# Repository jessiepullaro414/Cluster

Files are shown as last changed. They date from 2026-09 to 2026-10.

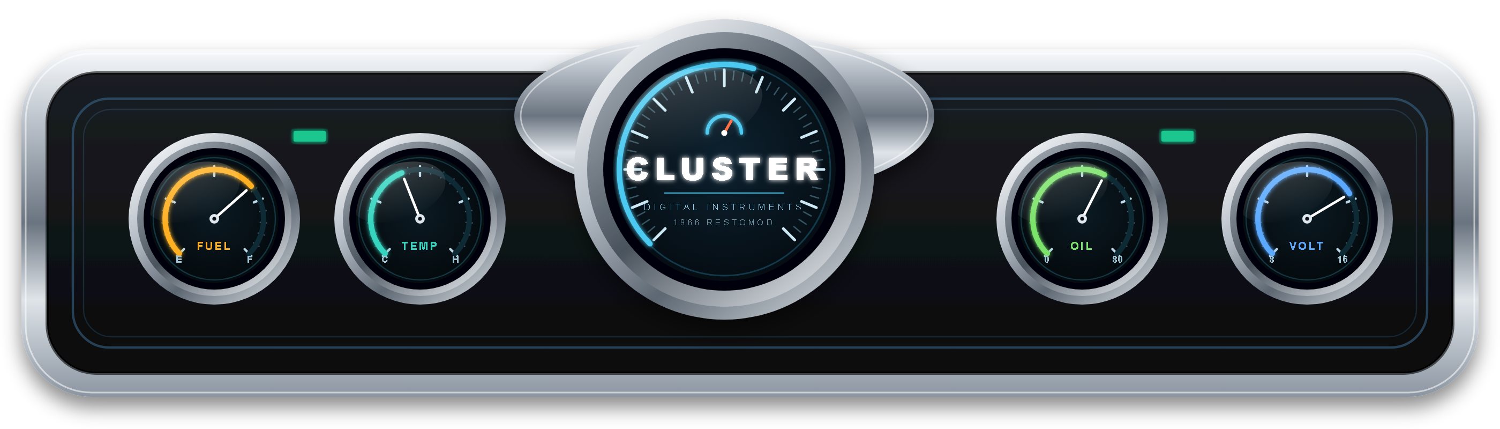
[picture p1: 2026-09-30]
media/cluster-dashboard.png

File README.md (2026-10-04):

# Cluster

Digital restomod instrument cluster for a 1966 Mustang: round displays in the stock round holes, custom reprinted faceplate, stock outer dash opening (457.2 x 116.69mm hard limit, 441.09 x 105.54mm inner).

The center gauge runs Android Automotive; the four small gauges are driven by a separate MCU board. Both boards share a CAN bus with `ecu-pcb`.

## Boards

| Dir | Role | Core | Board |
|---|---|---|---|
| [display/](display/) | Android center gauge | Toradex Verdin iMX95 SoM, 4in 800-nit round MIPI-DSI panel | about 152 x 102mm |
| [gauges/](gauges/) | 4 small aux gauges, resistive sender front end, Hall speed, tach and six 12 V indicator-lamp inputs | NXP S32K144, 4x GC9A01 round SPI | 447.1 x 58.3mm |

**Status: prototype, not yet ordered.** Both boards are routed with 0 unconnected nets and have generated BOMs (`ClusterDisplay_BOM.html`, `ClusterGauges_BOM.html`). display/ is ERC-clean (0 violations); gauges/ shows 4 known ERC items (a SWCLK pin, the MCU and buck supply pins flagged as undriven, and a `+5V` power-flag note). DRC on display/ reports 10 `solder_mask_bridge` errors that are the intentional open polarity jumpers JP1/JP2, plus silkscreen and library-copy warnings. Nothing has been fabricated, powered or firmware-tested. Mechanical fit in the dash is not yet checked against a 3D model, and gauges/ (447.1 mm) is wider than the 441.09 mm inner opening dimension, within the 457.2 mm outer limit.

## How the boards talk

gauges/ is the gateway. It is the only board that touches the car CAN bus (CAN0, receive-only in firmware) and it forwards filtered values to display/ over a private two-node CAN link (gauges/ CAN1 to display/ CAN). Android therefore cannot transmit on the vehicle bus. The protocol (`protocol/can_protocol.py`, revision 2) generates the DBC, a spec and a C header; the private link carries a rolling counter and CRC-8, and the car-bus side has a selectable Haltech V2 profile. Speed comes from a Hall-effect sender on gauges/ (for cable-driven cars) or from the ECU over CAN. gauges/ also reads six 12 V-active indicator lamps (left/right turn, high beam, brake, alternator, oil; each has a DNP pull-up for a ground-switched lamp) and a tach input (ECU or coil-driver output; coil-negative on a points ignition is not validated), sent to display/ in the `Indicators` message (which also carries the dimmer level) and the `Rpm` signal. display/ has a rotary-dial input (J11), an ignition wake circuit, and bench headers for the A55 console UART (J12), USB (J13), JTAG (J8) and buttons (J9).

## Known limits of the layouts

- Both boards are four-layer with GND on In1 and +5V / +3V3 poured on In2, but they are not solid planes: slow signals were routed on the inner layers by the autorouter and the pours fill around them. On display/ about 925 mm of signal wiring sits on In1 (none inside the DSI corridor, none under the +5V buck or the backlight boost, about 17 mm under the panel-bias converter) and about 790 mm on In2. On gauges/ about 3.9 m sits on In1 and 5.1 m on In2, because it is a 447 mm board with long runs to four displays. Forbidding signals on In1 left 6 to 122 connections unrouted, so it was not adopted.
- The panel DSI lanes on display/ are routed by `dsi_route.py` (about 10.6 to 11.2 mm per leg, at most 0.6 mm skew inside a pair) with an estimated 100 ohm differential geometry that has not been checked with a field solver.
- The panel connector, the panel polarity jumpers and the wake-pin polarity are unconfirmed (see `fab/README.md`).

Open items and rationale live in the working plan, not here. Panel: TSD TST040HDBC-42 (4in round, 800 nits, -30..+80C, fits the opening uncropped). Known TBDs: harness connectors J2/J3/J8/J9 on display/, the panel's unresolved +/-6.5V pin polarity (open solder jumpers JP1/JP2), CAN protocol, firmware.

## Workflow

Everything is generated from scripts. Never hand-edit the KiCad files; change the script and regenerate. In `display/` or `gauges/`:

```
python build_schematic.py   # schematic + ERC self-checks
python build_pcb.py         # placement + DRC-style self-checks
python route_board.py       # FreeRouting (display/ also adds the DSI pairs), verified against real kicad-cli DRC
python ../run_drc.py <Board>.kicad_pcb
python build_bom.py         # BOM with coverage/value-spelling checks
```

`route_board.py` needs `tools/freerouting-2.2.4.jar` (gitignored, ~57MB; download from the FreeRouting releases) and a JRE.

## Archive

[archive/](archive/) holds superseded work kept for reference only, not maintained:

- `single-board-s32k144-bt817aq/`: the original one-board design (S32K144 + BT817AQ + round ST7701S speedo + 4 GC9A01), fully routed 252/252 before the Android pivot.
- `.../sense-abandoned-bar-panel-attempt/`: an unfinished CAN-only sensor board from the abandoned wide bar-panel direction.

Scripts there use their old relative paths (`tools/`, `run_drc.py`) and will need adjusting to run.

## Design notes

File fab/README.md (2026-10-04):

# Fab package

Generated by `python fab/build_fab.py` from the routed boards. It refuses to package a board that has unconnected nets or an unexpected DRC category.

Per board (`fab/display/`, `fab/gauges/`):

| File | What it is |
|---|---|
| `<board>_fab.zip` | Gerbers (Protel extensions, X2) and Excellon drill (plated and non-plated separate). Upload this to the board house. |
| `<board>_bom.csv` | One line per orderable part: MPN, manufacturer, quantity, designators. Source for a Mouser/DigiKey cart. |
| `<board>_pos.csv` | Pick-and-place, only needed if the fab assembles. |
| `report.txt` | DRC status and counts. |

Also `fab/combined_bom.csv`: both boards' parts in one cart-ready list (quantities per board, so multiply by the number of boards you build).

## Order settings (both boards)

Checked against JLCPCB's published 4-layer capabilities (min trace/space 0.09 mm, min drill 0.15 mm, via 0.15/0.25 mm, silkscreen text at least 1.0 mm high and 0.15 mm stroke). These boards use 0.2 mm tracks and clearances, 0.3/0.6 mm vias, a smallest drill of 0.2 mm, and 1.0 mm / 0.15 mm silkscreen text, so they sit inside those limits.

- Layers: 4. Thickness: 1.6 mm. Outer copper 1 oz, inner copper 0.5 oz.
- Surface finish: **ENIG**. The panel connector is 0.3 mm pitch and the MCU, buck and QFN parts are 0.5 mm pitch; HASL is not recommended.
- Solder mask and silkscreen: your choice (the layout is drawn for dark mask with white silk). Black mask with white silk suits the dash.
- Impedance control: **request it for display/ if the fab offers it, with the DSI pairs as the controlled pairs.** The four DSI pairs are 0.25 mm tracks with a 0.25 to 0.5 mm gap on F.Cu over the In1 ground plane, about 10.6 to 11.2 mm per leg, with at most 0.6 mm (about 4 ps) skew inside a pair. By the IPC-2141 approximation that is about 100 ohm differential for a 0.21 mm prepreg; that is an estimate, so use the fab's own calculator and stackup and adjust width and gap if it disagrees. The P leg of each pair hops to B.Cu for about 3 mm to swap polarity order between the connectors (two 0.6/0.3 mm vias), where the reference is In2 rather than ground. (An earlier version of this page called uncontrolled impedance acceptable; the corrected layout is short enough that it matters less, but it is still a high-speed pair.)
- Quantity: 5 of each is the usual minimum.

## Board sizes

- display/: about 152 x 102 mm.
- gauges/: 447 x 56 mm. Check the board house's maximum length for your chosen service (the long side is under 500 mm).

## What is still unconfirmed (could force a respin of display/)

1. The panel FPC connector (Hirose FH26-39S-0.3SHW) is inferred from the panel datasheet; the datasheet names no connector. Ask TSD (draft in `docs/rfq-drafts.md`).
2. The panel's +/-6.5 V pin polarity is contradictory in its datasheet; the board has open solder jumpers JP1/JP2 for either answer.
3. The Verdin wake-pin polarity is unstated; the circuit assumes a software-selectable edge.

gauges/ has no open hardware question other than the AutoMeter sender wiring (assumed harness-powered, signal and ground only).

## Parts

Every active part and connector has a real orderable part number. Passives come from `tools/passive_catalog.py`; entries marked PATTERN in the BOM follow the manufacturer's numbering scheme with neighbouring parts verified, and should be confirmed in the distributor cart. Live pricing and stock are not included.

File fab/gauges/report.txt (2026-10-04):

gauges fab package
  DRC: unconnected 0, accepted findings {'silk_edge_clearance': 4, 'lib_footprint_mismatch': 8, 'silk_overlap': 1, 'silk_over_copper': 1}
  parts 137, BOM lines 59, lines needing part selection 0
  gerbers: ['ClusterGauges-B_Cu.gbl', 'ClusterGauges-B_Mask.gbs', 'ClusterGauges-B_Paste.gbp', 'ClusterGauges-B_Silkscreen.gbo', 'ClusterGauges-Edge_Cuts.gm1', 'ClusterGauges-F_Cu.gtl', 'ClusterGauges-F_Mask.gts', 'ClusterGauges-F_Paste.gtp', 'ClusterGauges-F_Silkscreen.gto', 'ClusterGauges-In1_Cu.g1', 'ClusterGauges-In2_Cu.g2', 'ClusterGauges-NPTH-drl_map.gbr', 'ClusterGauges-NPTH.drl', 'ClusterGauges-PTH-drl_map.gbr', 'ClusterGauges-PTH.drl', 'ClusterGauges-job.gbrjob']

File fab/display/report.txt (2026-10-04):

display fab package
  DRC: unconnected 0, accepted findings {'solder_mask_bridge(JP1/JP2 open jumpers, intended)': 10, 'lib_footprint_mismatch': 11, 'silk_overlap': 2, 'silk_over_copper': 4}
  parts 115, BOM lines 67, lines needing part selection 2
  gerbers: ['ClusterDisplay-B_Cu.gbl', 'ClusterDisplay-B_Mask.gbs', 'ClusterDisplay-B_Paste.gbp', 'ClusterDisplay-B_Silkscreen.gbo', 'ClusterDisplay-Edge_Cuts.gm1', 'ClusterDisplay-F_Cu.gtl', 'ClusterDisplay-F_Mask.gts', 'ClusterDisplay-F_Paste.gtp', 'ClusterDisplay-F_Silkscreen.gto', 'ClusterDisplay-In1_Cu.g1', 'ClusterDisplay-In2_Cu.g2', 'ClusterDisplay-NPTH-drl_map.gbr', 'ClusterDisplay-NPTH.drl', 'ClusterDisplay-PTH-drl_map.gbr', 'ClusterDisplay-PTH.drl', 'ClusterDisplay-job.gbrjob']

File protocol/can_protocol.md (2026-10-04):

# Cluster CAN protocol, rev 2 (proposal)

Generated by `can_protocol.py`; do not edit by hand.

gauges/ is the gateway: only it is on the car bus (listen-only). display/ talks to gauges/ over a private link. See the plan for the topology and the reasons.

## Private link (gauges/ <-> display/)

Little-endian, 500 kbit/s (proposed). Messages with `Counter` and `Crc8` end with a 4-bit rolling counter (bits 52-55) and CRC-8 SAE J1850 (poly 0x1D, init 0xFF, final XOR 0xFF) over bytes 0-6. Missing display heartbeat for 1500 ms means DisplayOffline.

| ID | Name | Sender | Period | DLC |
|---|---|---|---|---|
| 0x300 | VehicleMotion | GAUGES | 50 ms | 8 |
| 0x302 | VehicleFluids | GAUGES | 100 ms | 8 |
| 0x303 | Indicators | GAUGES | 100 ms | 8 |
| 0x301 | GaugesStatus | GAUGES | 1000 ms | 8 |
| 0x310 | PowerState | GAUGES | 500 ms | 8 |
| 0x400 | DisplaySettings | DISPLAY | 1000 ms | 8 |
| 0x410 | SpeedCalibration | DISPLAY | 1000 ms | 8 |
| 0x420 | InputConfig | DISPLAY | 1000 ms | 8 |
| 0x4F0 | DisplayHeartbeat | DISPLAY | 1000 ms | 8 |

### 0x300 VehicleMotion (GAUGES, 50 ms)

Consolidated motion data, chosen by gauges/ from the Hall input and the car bus.

| Signal | Start bit | Length | Scale | Offset | Range | Unit |
|---|---|---|---|---|---|---|
| SpeedKph | 0 | 16 | 0.1 | 0 | 0..400 | km/h |
| Rpm | 16 | 16 | 1 | 0 | 0..12000 | rpm |
| BatteryV | 32 | 16 | 0.01 | 0 | 0..20 | V |
| SpeedValid | 48 | 1 | 1 | 0 | 0..1 |  |
| RpmValid | 49 | 1 | 1 | 0 | 0..1 |  |
| BatteryValid | 50 | 1 | 1 | 0 | 0..1 |  |
| SpeedFromHall | 51 | 1 | 1 | 0 | 0..1 |  |
| Counter | 52 | 4 | 1 | 0 | 0..15 |  |
| Crc8 | 56 | 8 | 1 | 0 | 0..255 |  |

### 0x302 VehicleFluids (GAUGES, 100 ms)

Consolidated fluid data: ECU value if fresh, else local sender.

| Signal | Start bit | Length | Scale | Offset | Range | Unit |
|---|---|---|---|---|---|---|
| FuelPct | 0 | 16 | 0.01 | 0 | 0..100 | % |
| CoolantC | 16 | 16 signed | 0.1 | 0 | -40..150 | degC |
| OilKpa | 32 | 16 | 0.1 | 0 | 0..1000 | kPa |
| FuelValid | 48 | 1 | 1 | 0 | 0..1 |  |
| CoolantValid | 49 | 1 | 1 | 0 | 0..1 |  |
| OilValid | 50 | 1 | 1 | 0 | 0..1 |  |
| Counter | 52 | 4 | 1 | 0 | 0..15 |  |
| Crc8 | 56 | 8 | 1 | 0 | 0..255 |  |

### 0x303 Indicators (GAUGES, 100 ms)

Indicator-lamp states from the six 12 V lamp inputs on gauges/ (1 = lamp on after the per-channel polarity setting), sent every 100 ms and on every change.

| Signal | Start bit | Length | Scale | Offset | Range | Unit |
|---|---|---|---|---|---|---|
| TurnLeft | 0 | 1 | 1 | 0 | 0..1 |  |
| TurnRight | 1 | 1 | 1 | 0 | 0..1 |  |
| HighBeam | 2 | 1 | 1 | 0 | 0..1 |  |
| BrakeWarning | 3 | 1 | 1 | 0 | 0..1 |  |
| AlternatorWarning | 4 | 1 | 1 | 0 | 0..1 |  |
| OilWarning | 5 | 1 | 1 | 0 | 0..1 |  |
| DashLightsOn | 6 | 1 | 1 | 0 | 0..1 |  |
| DashDimmerPct | 8 | 8 | 1 | 0 | 0..100 | % |
| Counter | 52 | 4 | 1 | 0 | 0..15 |  |
| Crc8 | 56 | 8 | 1 | 0 | 0..255 |  |

### 0x301 GaugesStatus (GAUGES, 1000 ms)

Health, identity and where each value currently comes from.

| Signal | Start bit | Length | Scale | Offset | Range | Unit |
|---|---|---|---|---|---|---|
| FwMajor | 0 | 8 | 1 | 0 | 0..255 |  |
| FwMinor | 8 | 8 | 1 | 0 | 0..255 |  |
| FuelSenderOpen | 16 | 1 | 1 | 0 | 0..1 |  |
| OilSenderOpen | 17 | 1 | 1 | 0 | 0..1 |  |
| TempSenderOpen | 18 | 1 | 1 | 0 | 0..1 |  |
| CarBusActive | 19 | 1 | 1 | 0 | 0..1 |  |
| FuelFromCar | 20 | 1 | 1 | 0 | 0..1 |  |
| CoolantFromCar | 21 | 1 | 1 | 0 | 0..1 |  |
| OilFromCar | 22 | 1 | 1 | 0 | 0..1 |  |
| BatteryFromCar | 23 | 1 | 1 | 0 | 0..1 |  |
| ActiveProfile | 24 | 8 | 1 | 0 | 0..255 |  |
| DisplayOffline | 32 | 1 | 1 | 0 | 0..1 |  |
| RpmFromTach | 33 | 1 | 1 | 0 | 0..1 |  |

### 0x310 PowerState (GAUGES, 500 ms)

Ignition and sleep coordination; also sent on every change.

| Signal | Start bit | Length | Scale | Offset | Range | Unit |
|---|---|---|---|---|---|---|
| IgnitionOn | 0 | 1 | 1 | 0 | 0..1 |  |
| SuspendRequest | 1 | 1 | 1 | 0 | 0..1 |  |
| SuspendInSeconds | 8 | 8 | 1 | 0 | 0..255 | s |
| Counter | 52 | 4 | 1 | 0 | 0..15 |  |
| Crc8 | 56 | 8 | 1 | 0 | 0..255 |  |

### 0x400 DisplaySettings (DISPLAY, 1000 ms)

Persistent settings owned by Android; sent on change and every second. gauges/ keeps the last copy in flash.

| Signal | Start bit | Length | Scale | Offset | Range | Unit |
|---|---|---|---|---|---|---|
| BrightnessPct | 0 | 8 | 1 | 0 | 0..100 | % |
| NightMode | 8 | 1 | 1 | 0 | 0..1 |  |
| UnitsMph | 9 | 1 | 1 | 0 | 0..1 |  |
| CarProfile | 16 | 8 | 1 | 0 | 0..255 |  |
| CarBitrate | 24 | 2 | 1 | 0 | 0..3 |  |
| TankCapacityL | 32 | 16 | 0.1 | 0 | 0..200 | L |
| Counter | 52 | 4 | 1 | 0 | 0..15 |  |
| Crc8 | 56 | 8 | 1 | 0 | 0..255 |  |

### 0x410 SpeedCalibration (DISPLAY, 1000 ms)

Pulses per mile for the Hall sender (AutoMeter 16-pulse sender at 1000 rev/mile = 16000).

| Signal | Start bit | Length | Scale | Offset | Range | Unit |
|---|---|---|---|---|---|---|
| PulsesPerMile | 0 | 32 | 1 | 0 | 100..200000 |  |
| Counter | 52 | 4 | 1 | 0 | 0..15 |  |
| Crc8 | 56 | 8 | 1 | 0 | 0..255 |  |

### 0x420 InputConfig (DISPLAY, 1000 ms)

Per-input options for the lamp and tach inputs on gauges/. A lamp wired ground-switched (the DNP pull-up fitted) idles high, so its bit here is set to invert it.

| Signal | Start bit | Length | Scale | Offset | Range | Unit |
|---|---|---|---|---|---|---|
| LampInvertMask | 0 | 8 | 1 | 0 | 0..63 |  |
| TachEnabled | 8 | 1 | 1 | 0 | 0..1 |  |
| TachPulsesPerRev | 16 | 8 | 1 | 0 | 1..16 |  |
| Counter | 52 | 4 | 1 | 0 | 0..15 |  |
| Crc8 | 56 | 8 | 1 | 0 | 0..255 |  |

### 0x4F0 DisplayHeartbeat (DISPLAY, 1000 ms)

Liveness plus coarse state; gauges/ marks the display offline if this stops.

| Signal | Start bit | Length | Scale | Offset | Range | Unit |
|---|---|---|---|---|---|---|
| State | 0 | 2 | 1 | 0 | 0..3 |  |
| Counter | 52 | 4 | 1 | 0 | 0..15 |  |
| Crc8 | 56 | 8 | 1 | 0 | 0..255 |  |

## Car bus: Haltech V2.35.0 subset (read only)

Big-endian, 11-bit IDs, 1 Mbit/s on Haltech (the bit rate is a setting). Layout verified against Haltech's PDF on 2026-09-30. Oil pressure and coolant/fuel pressure are absolute kPa minus 101.3. Temperatures are kelvin. Car-bus frames older than 500 ms are stale.

| ID | Name | Sender | Period | DLC |
|---|---|---|---|---|
| 0x360 | HaltechEngine | ECU | 20 ms | 8 |
| 0x361 | HaltechPressures | ECU | 20 ms | 8 |
| 0x370 | HaltechSpeed | ECU | 50 ms | 8 |
| 0x372 | HaltechBattery | ECU | 100 ms | 8 |
| 0x3E0 | HaltechTemps | ECU | 200 ms | 8 |
| 0x3E2 | HaltechFuelLevel | ECU | 200 ms | 8 |

### 0x360 HaltechEngine (ECU, 20 ms)

RPM, manifold pressure (absolute), throttle, coolant pressure.

| Signal | Start bit | Length | Scale | Offset | Range | Unit |
|---|---|---|---|---|---|---|
| Rpm | 7 | 16 | 1 | 0 | 0..20000 | rpm |
| MapKpaAbs | 23 | 16 | 0.1 | 0 | 0..1000 | kPa |
| ThrottlePct | 39 | 16 | 0.1 | 0 | 0..100 | % |
| CoolantPressureKpa | 55 | 16 | 0.1 | -101.3 | -101.3..1000 | kPa |

### 0x361 HaltechPressures (ECU, 20 ms)

Fuel pressure, oil pressure (absolute minus 101.3), demand.

| Signal | Start bit | Length | Scale | Offset | Range | Unit |
|---|---|---|---|---|---|---|
| FuelPressureKpa | 7 | 16 | 0.1 | -101.3 | -101.3..1000 | kPa |
| OilPressureKpa | 23 | 16 | 0.1 | -101.3 | -101.3..1000 | kPa |
| EngineDemandPct | 39 | 16 | 0.1 | 0 | 0..400 | % |

### 0x370 HaltechSpeed (ECU, 50 ms)

Vehicle speed (only sent if the ECU's speed input is set up).

| Signal | Start bit | Length | Scale | Offset | Range | Unit |
|---|---|---|---|---|---|---|
| VehicleSpeedKph | 7 | 16 | 0.1 | 0 | 0..400 | km/h |

### 0x372 HaltechBattery (ECU, 100 ms)

Battery voltage.

| Signal | Start bit | Length | Scale | Offset | Range | Unit |
|---|---|---|---|---|---|---|
| BatteryV | 7 | 16 | 0.1 | 0 | 0..30 | V |

### 0x3E0 HaltechTemps (ECU, 200 ms)

Temperatures in kelvin (x/10).

| Signal | Start bit | Length | Scale | Offset | Range | Unit |
|---|---|---|---|---|---|---|
| CoolantTempK | 7 | 16 | 0.1 | 0 | 0..500 | K |
| AirTempK | 23 | 16 | 0.1 | 0 | 0..500 | K |
| FuelTempK | 39 | 16 | 0.1 | 0 | 0..500 | K |
| OilTempK | 55 | 16 | 0.1 | 0 | 0..500 | K |

### 0x3E2 HaltechFuelLevel (ECU, 200 ms)

Fuel level in litres (x/10).

| Signal | Start bit | Length | Scale | Offset | Range | Unit |
|---|---|---|---|---|---|---|
| FuelLevelL | 7 | 16 | 0.1 | 0 | 0..500 | L |

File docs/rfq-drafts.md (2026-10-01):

# RFQ drafts (not sent)

Drafts for the two vendor questions that block hardware ordering. Edit the sender details and send them yourself; nothing here has been sent.

## 1. Team Source Display: TST040HDBC-42 (4.0in round, 720x720, MIPI)

Subject: TST040HDBC-42 (V1.0, 2023-06-29): questions before a prototype order

Hello,

We are designing a carrier board around your TST040HDBC-42 for an automotive instrument cluster (one unit per board, prototype quantity first). Your datasheet V1.0 leaves a few points open, and one point is contradictory. Could you confirm:

1. **Analog supply pins.** The interface table (section 3) lists pins 7-8 as VSP (+6.5 V) and pins 10-11 as VSN (-6.5 V). The mechanical drawing's pin header row shows pins 7-8 as VDD(-6.3 V) and pins 10-11 as VDD(+6.3 V). Which is correct, and what are the exact voltage tolerances? Please also give the supply currents (input current is listed as TBD).
2. **FPC.** What connector mates with the 39-pin FPC (we assume 0.3 mm pitch from the 12 mm tail width)? Which side are the contact fingers on, and can the FPC be built with the fingers facing either direction?
3. **Initialisation.** Please send the ICNL9707 initialisation command sequence (DCS) and the recommended DSI timings: lane count (we plan 3 lanes), clock rate, porches, refresh rate.
4. **Power sequencing.** The required order and timing for IOVCC, VSP/VSN, reset and the backlight.
5. **Backlight.** The backlight is listed as 20 LEDs, 180 mA, Vf 15 V. Is that 5 series x 4 parallel? What is the maximum current at 80 C ambient, and what PWM dimming frequency range do you recommend if we dim with PWM?
6. **Commercial.** Price at 5 and 50 pieces, minimum order quantity, lead time, and whether the module is in current production.
7. **Environment.** Is the -30 to +80 C operating rating at full brightness, and is there a derating curve for backlight current versus temperature?

Thank you,
(name)

## 2. Toradex: Verdin iMX95 in an Android Automotive instrument cluster

Subject: Verdin iMX95 (PN 0089): Android Automotive support and suspend behaviour

Hello,

We are building a custom carrier for the Verdin iMX95 Hexa 8GB WB IT (0089, V1.1B) as an Android Automotive instrument cluster. Could you tell us:

1. Is there a Toradex-supported or planned path for Android or Android Automotive on the production Verdin iMX95? NXP's automotive-16.0.0_1.3.0 lists only the NXP i.MX 95 19x19 EVK, and the Verdin EVK is end of life.
2. Which development carrier should we use with the iMX95 module (the Verdin EVK replacement, PN 05241104, or a Verdin Development Board)?
3. Does the module support suspend-to-RAM with wake on CTRL_WAKE1_MICO# (X1 pin 252)? What is the typical suspend current of the module, and what is the resume time to first frame? Is the wake input active-low and level or edge triggered?
4. Where can we find the System Manager board configuration for the production module, since NXP's tree builds the System Manager with the EVK regulator configuration?
5. Is a power consumption table (typical and maximum VCC current) available yet?

Thank you,
(name)

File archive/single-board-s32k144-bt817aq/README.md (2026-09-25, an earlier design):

# Cluster — KiCad schematic + PCB

Companion KiCad project for "Cluster": a fully digital instrument cluster
that drops into a **stock 1966 Ford Mustang gauge housing**. Sibling to
[`manifold-pcb`](https://github.com/jessiepullaro414/Manifold),
[`ecu-pcb`](https://github.com/jessiepullaro414/ecu-pcb), and
[`thermo-pcb`](https://github.com/jessiepullaro414/Thermo) — same
12V/automotive-grade discipline, same kiutils/kicad-cli script-driven
workflow (see the sibling projects' READMEs for the toolchain itself).

## RE-ARCHITECTED 2026-09-25 — read this before anything below

Everything under "Status" and most of this document describes
**Cluster's original, now-superseded architecture**: one NXP S32K144
hub MCU driving all 5 displays directly (4x GC9A01 + a BT817AQ co-
processor for the center speedo). That design finished fully routed
(252/252 nets, DRC-clean) before being replaced.

**Current real architecture is TWO boards**, restomod-style (classic
round-hole layout preserved, Android specifically on the center
display, since the Android-capable chip can only drive one display -
see each board's own header for the full reasoning):

- **`display/`** — Verdin iMX95 SoM (ported from `fascia-pcb`) driving
  ONE round panel (real target: DisplayModule DM-TFTR50-413, 5.0",
  1080x1080, native MIPI-DSI) behind the center opening, running
  Android Automotive. Direct DSI, no bridge chip. Schematic ERC-clean.
- **`gauges/`** — the original S32K144 design with the center speedo
  subsystem removed: still drives the 4 small round GC9A01 aux gauges
  (fuel/oil/coolant temp/battery) locally, still reads the real
  resistive senders / CAN0 to `ecu-pcb`. Schematic ERC-clean.

The two boards (plus `ecu-pcb`) share ONE real CAN0 bus - `display/`
pushes Android's aggregated gauge data to `gauges/`'s small displays
over it, per the user's own request for the boards to communicate.

The top-level `Cluster.kicad_sch`/`build_schematic.py`/`build_pcb.py`/
`route_board.py` files below are the OLD, superseded design - kept for
reference, not being built on. A `sense/` directory also exists from an
intermediate, abandoned direction (CAN-only sensor board, before the
user clarified the 4 small gauges should stay locally displayed) - it
was never committed and can be deleted.

## Status (of the OLD, superseded design below this point)

**Schematic is fully wired and ERC-clean as of 2026-09-22.** All 6 steps
of the build-out plan are done: S32K144 peripheral pin-mux (real, from
NXP's own Reference Manual), CAN0 transceiver (reused from `ecu-pcb`),
4x GC9A01 aux gauges (real Raystar pinout), BT817AQ speedo co-processor
+ ST7701S module (real Bridgetek/Panox pinouts — including a genuinely
new VCC1V2 LDO rail this required, see below), the sensor ADC front
end, and the CAN0+sensor harness connector. `kicad-cli sch erc` is down
to exactly the 4 baseline tool-limitation findings every sibling
board's *finished* schematic carries (power pins ERC can't trace
through a passive; SWCLK driven off-sheet by the debug probe) — zero
unexpected results, zero guessed pins or values anywhere in the file.

**PCB is placed and fully routed as of 2026-09-23** (see "PCB layout"
below for the full placement history). `route_board.py` (new this
session, adapted from `thermo-pcb`'s own FreeRouting DSN/SES pipeline)
got **252/252 nets, 0 unrouted**, on a clean regenerate-and-route
cycle (FreeRouting is stochastic — an earlier attempt landed 251/252
with one net needing a hand-route; re-exporting the board and routing
again converged fully). `kicad-cli pcb drc` on the routed board is
clean except the same documented categories the unrouted board
already had — nothing new introduced by routing itself.

**Not started yet:** the real contoured board outline (currently a
plain rectangle) and BOM. Also still open: the physical bezel
outer-envelope measurement (README's own open item below) and the
firmware CAN-vs-local-sender priority policy — neither blocks the
work still open above.

## Why this project exists

The stock '66 Mustang cluster (2 small gauges — 1 large speedo — 2 small
gauges, chrome bezel) is being replaced with 5 independent digital
displays, one per opening, driven by real sensor data — either the car's
**existing resistive senders** (fuel, oil pressure, coolant temp) read
directly, or **digital values over CAN** from `ecu-pcb` when it's
installed. The **outer bezel envelope must stay stock** so the cluster
still fits the factory dash cutout with no cutting; the individual gauge
*openings* are free to grow, because the chrome faceplate itself is being
reprinted rather than reused.

## Real mechanical reference (user-supplied dimensioned drawing, 2026-09-23)

The user supplied a real dimensioned reference drawing — **the
*inside* dash-opening dimensions, not the decorative outer chrome
bezel** (that's a separate, larger trim piece that overlaps the dash
surface around this opening; not dimensioned here) — with all 5 gauge
openings called out via a width x height / diameter legend. This
supersedes the earlier web-researched approximations below, which are
kept only for the sender/sensor research that's still independently
useful.

| Feature | Size (real, from the reference drawing) |
|---|---|
| Dash opening (outer, the hole everything must fit through) | 18.00" x 4.594" (457.2 x 116.69mm) |
| Inner panel dimension (inside the opening) | 17.361" x 4.155" (441.09 x 105.54mm) |
| Center speedo opening | dia 3.60" (91.44mm) |
| 4x auxiliary gauge openings | dia 1.810" each (45.97mm) |

**This closes the "overall bezel outer envelope" open item** — PCB
layout can now target a real outline that fits within this dash
opening (18.00" x 4.594" is the hard outer limit; 17.361" x 4.155" is
the real usable inner dimension once inside it). The separate chrome
trim ring shown in the very first reference photo is NOT yet
dimensioned — it's cosmetic (screws to the dash face over this
opening) and doesn't constrain the board's own size the way the
opening itself does. Exact hole-center X positions along the row
aren't individually dimensioned on the drawing — inferred
proportionally from it for first-pass placement, refined once real FPC
connector positions are chosen during layout.

Earlier web research (kept for the sender/sensor findings, which don't
depend on the exact bezel dimensions):
- Speedo opening was earlier estimated at 3-3/8" (85.7mm) face / 3-7/16"
  (87.3mm) mount hole — the real drawing's 3.60" (91.44mm) is close but
  not identical; use the real drawing's number.
- Aux gauge openings were earlier estimated at 2-1/16" (52.4mm) stock —
  the real drawing's 1.810" (45.97mm) is meaningfully smaller; use the
  real drawing's number. (The "up to 2-5/8" with a modified bezel"
  headroom claim was about reproduction-housing tolerance, not this
  specific drawing — worth a sanity check once real displays are in
  hand, but the reprinted-faceplate opening can be sized to whatever the
  chosen display module actually needs regardless.)

## Real sensor reference (verified against '65-'66 Mustang service data)

All four stock small-gauge positions share the same resistive-sender
gauge movement, **except** the "amp" gauge, which Ford wired in 1966 as a
voltage-drop sensor in series with the charging circuit, not a true
resistive sender — the common owner upgrade (confirmed across multiple
Mustang forums) is to just wire a real voltmeter into that position
instead of reproducing the factory ammeter's quirky behavior. Digital
Cluster does the same: that position reads **battery/alternator voltage
directly** through a divider, no sender curve needed.

The other three are genuine non-linear resistive senders (same
"log-scale, firmware does the lookup" treatment `thermo-pcb` already
uses for its own resistive temp sender):

| Gauge | Sender range | Reference points |
|---|---|---|
| Fuel level | ~10Ω (full) – ~73Ω (empty) | wire-wound rheostat float sender |
| Oil pressure | ~10Ω (full pressure) – ~70Ω (zero) | log scale — halfway reads 31.6Ω, not 40Ω |
| Coolant temp | ~10Ω (250°F) – ~300Ω (70°F) | genuine Ford spec: 19Ω @ 200°F |

Firmware scope this adds (same category as `thermo-pcb`'s NTC lookup):
3 non-linear resistance-to-value lookup tables, plus one linear
voltage-divider scale for the 4th position.

## Electrical architecture (locked 2026-09-22)

Two decisions were made explicitly rather than guessed:

1. **One hub board, one MCU, 5 SPI-driven displays** — not 5 independent
   smart-display modules on a backbone bus. Matches how `manifold-pcb`
   and `thermo-pcb` are built (single board, single BOM, single firmware
   image) rather than `fascia-pcb`'s split-board approach, which only
   exists there because that panel is physically detached across the
   dash — Cluster's 5 openings are all in one housing, so there's no
   equivalent reason to split.
2. **Center speedo stays large-format, the 4 aux positions keep their
   classic sender-driven roles** (fuel / coolant temp / oil pressure /
   battery voltage) rather than repurposing a position for a
   CAN-sourced tach — keeps the cluster reading like the original car at
   a glance.

**Displays** (both real, sourceable SPI round TFT parts):
- **4x auxiliary gauges:** GC9A01 driver, 1.28", 240x240, IPS, genuine
  4-wire SPI (SCK/MOSI/CS/DC/RST — 5 signal pins, no parallel bus). Fits
  comfortably inside the stock 2-1/16" opening with room to spare, or the
  up-sized 2-5/8" opening if the faceplate goes bigger.
- **1x center speedo:** ST7701S driver, 2.1", 480x480, IPS. This part is
  configured over a thin SPI control link but its actual pixel data path
  is an **18-bit parallel RGB bus**, not 4-wire SPI — a meaningfully
  bigger GPIO/bandwidth cost than the 4 aux displays, not just "a bigger
  version of the same wiring." Flagged as its own interface class for the
  MCU pin-budget pass below.

**Data sources, both live at once:**
- **CAN:** reuse `ecu-pcb`'s real TJA1043T transceiver + FlexCAN wiring
  pattern, one channel tied to the vehicle/`ecu-pcb` bus, for cars running
  that ECU.
- **Local senders:** ADC channels + pull-up dividers reading the fuel/
  oil/temp senders directly (same divider-into-ADC topology `thermo-pcb`
  uses for its own resistive sender) plus one divider on battery voltage
  — for cars without `ecu-pcb`, or as a live fallback when it's present
  but not transmitting.
- Both paths are wired in hardware simultaneously; which one a given
  gauge trusts at any moment is a **firmware policy**, not a board
  variant or a physical switch (open item below).

**MCU:** defaults to NXP S32K144 (the same AEC-Q100 Cortex-M4F part
`manifold-pcb`/`thermo-pcb` already use) rather than `ecu-pcb`'s
Qorivva MPC5606B — Cluster has no microsecond-level real-time firing to
do, so there's no reason to inherit the Qorivva's eMIOS-class timing
hardware.

## MCU pin/peripheral budget (real, verified 2026-09-22)

*Update, same day:* the real pin-by-pin assignment (which physical
S32K144 pad each LPSPI/FlexCAN0/ADC/GPIO signal lands on) is now done —
see `build_schematic.py`'s own citation comment above U1's registration
for the full real list, pulled from the Reference Manual's own embedded
IO-signal-table attachment. The budget estimate below held up: 25 real
pins claimed, no conflicts, comfortable headroom left on the 64-pin
package.

Pulled directly from NXP's own S32K1xx Data Sheet (Rev. 15, 5 March 2026,
Figure 3 "S32K1xx product series comparison" — the real per-part
comparison table, not a generic family blurb). **S32K144 real numbers:**
80 MHz (112 MHz HSRUN), up to 89 I/Os (100-pin LQFP/100-pin MAPBGA
package — the 64-pin LQFP `manifold-pcb`/`thermo-pcb` use has fewer),
**3x LPSPI**, **3x FlexCAN** (1 with CAN-FD), **2x 12-bit ADC x 16
channels = 32 channels total**, **1x FlexIO with only 8 configurable
pins** (documented purpose: UART/SPI/I2C/I2S protocol emulation — not
sized for a parallel display bus), no dedicated LCD/display controller
peripheral of any kind.

**The 4 aux gauges + CAN + local senders fit easily, even on the small
64-pin package**: 1 shared LPSPI bus (SCK+MOSI) + 4 CS + 4 DC + 1 shared
RST for the GC9A01s (~11 pins), 1 FlexCAN instance (2 pins), 4 ADC
channels (fuel/oil/temp/battery), plus the ~9 fixed pins every sibling
board already reserves for crystal/SWD/RESET/power — comfortably under
the ~58 GPIO the 64-pin package leaves after fixed pins.

**The center ST7701S speedo is a real, confirmed blocker, not a tight
budget.** Pulled Sitronix's real ST7701S datasheet (Preliminary V0.1,
2016/12) directly: its own Features section states it is a
**"Single chip WVGA a-Si TFT-LCD Controller/Driver *without Display
RAM*."** Checked the full IM[3:0] interface-mode table (Table 10, all 9
valid combinations) — every single mode is either MIPI DSI or
`RGB + n-bit SPI`, and in every RGB mode the SPI lines (CSX/SCL/SDA/DCX)
are documented as command/register-only; actual pixel data always goes
over the 16-24 line parallel `DB[23:0]` bus plus PCLK/VS/HS/DE. There is
no SPI-only mode with internal frame buffer, unlike the aux gauges'
GC9A01 (which does have internal GRAM and is genuinely SPI-only). That
means the host has to continuously stream a live video signal at the
panel's real refresh rate for as long as the display is on — and the
S32K144 has neither the ~20+ spare dedicated pins nor any peripheral
(FlexIO's 8 pins are the closest thing, and aren't remotely enough) to
generate that signal. **This isn't a pin-count-is-tight problem, it's a
peripheral-doesn't-exist problem** — no amount of re-budgeting the aux
gauges' pins fixes it.

## Center speedo: display co-processor (decided 2026-09-22)

Real, automotive-qualified answer found and chosen — a **Bridgetek
BT817AQ** ("BT817A Automotive Advanced Video Engine"), verified directly
from its own datasheet:

- **AEC-Q100 Grade 2** (-40 to 105°C), VQFN-64 — genuinely automotive,
  not a consumer part pressed into service.
- **QSPI to the host MCU** (up to 30MHz, SPI mode 0, single/dual/quad
  configurable) — a third LPSPI instance on the S32K144 (of the 3
  available, with one already used for the aux gauges) drives this with
  no contention.
- **29-signal parallel RGB output** (DISP/PCLK/VSYNC/HSYNC/DE + 8 bits
  each R/G/B), PCLK up to 96MHz, natively supports 1280x800/800x600/
  800x480 and is register-programmable for any timing in between —
  480x480 is comfortably within range. This feeds the ST7701S module's
  RGB input directly; BT817AQ becomes the thing that continuously
  generates the video stream the ST7701S needs, not the S32K144.
- Real bonus, not just a workaround: BT817AQ is part of Bridgetek's
  **EVE (Embedded Video Engine)** family — it has on-chip "Display List
  RAM" and a command-list graphics engine (lines, arcs, rotated bitmaps,
  text), so the S32K144 sends compact drawing commands ("needle at this
  angle") over QSPI rather than pushing a raw framebuffer — meaningfully
  simpler firmware than bit-pushing would have been even if the S32K144
  *could* drive the RGB bus itself.

This keeps the "one hub MCU reads sensors/CAN and makes decisions"
architecture intact — BT817AQ is a fixed-function rendering helper, the
same role `fascia-pcb`'s SN65DSI85-Q1 bridge plays for its own display,
not a second brain.

*Update 2026-09-22 (plan Step 4, now done):* pin-level wiring is
complete — the ST7701S module's 3-wire serial init (SDA/SCK/CS, plus a
4th spare GPIO for its RESET pin) lands on BT817AQ's own spare GPIO0-3,
keeping speedo init self-contained as planned. One real thing the
architecture pass above didn't catch: BT817A's digital core rail
(VCC1V2) turned out to be a genuine external 1.28V supply, not
internally regulated from VCC — a new TPS7A16-Q1 adjustable LDO
(AEC-Q100) + FB divider was added specifically for it. Real RGB666
wiring (BT817AQ's 24-bit RGB output down to the module's 18-bit input)
follows the module's own documented bit order, not a guess.

## Known open items (real, not placeholder — none of this is guessed)

1. **Overall bezel outer envelope** — needs a real caliper measurement of
   the physical stock cluster, not a web lookup. This is now the
   binding blocker on PCB layout specifically: the board's real shape
   has to roughly match the bezel's own 2-small/1-large/2-small plan
   view (see `build_schematic.py`'s own header on why this is genuinely
   new territory, not a copy of any sibling board's sizing model).
2. **Firmware source-priority policy** (CAN vs. local sender per gauge,
   and fallback behavior) — doesn't block hardware work, needed before
   firmware bring-up.
3. **PCB layout: placement done 2026-09-23, DRC-clean (unrouted).**
   `build_pcb.py` places all 74 real parts. The 5 display connectors
   (J3 speedo + 4x GC9A01 aux gauges) sit in a row along the board's
   bottom edge at evenly-spaced X positions (real hole-center spacing
   isn't individually dimensioned in the user's reference image, only
   sizes — explicit, flagged estimate, confirmed with the user as the
   right way to proceed rather than blocking). Everything else is
   organized into real functional zones spread across the full width —
   each display gets its own small local cluster of support parts
   directly above it (backlight resistor/cap; the speedo's whole
   BT817AQ+LDO+crystal subsystem sits above J3), and the board-wide
   subsystems (power input, MCU, CAN0, the aux-gauge backlight switch,
   the sender dividers) are arranged left-to-right above those.

   Board is **447.1 x 51.3mm**. The width genuinely can't shrink below
   the real 441mm target (the 5 connectors have to reach across the
   dash opening's real width to land under their own gauge holes,
   regardless of how little circuitry exists) — but the height started
   at 102.5mm only because the code anchored the display row to the
   *opening's own* 105.5mm inner height, which nothing actually
   requires the board to fill (user: "i think we can make it smaller.
   no reason to make it so big right?" — correct). Reworked to size
   height from the real, packed content instead (bottom margin +
   display row + each display's own local cluster + the core
   subsystems, stacked) — landed at 51.3mm, under half the original,
   still comfortably inside the 116.69mm hard limit.

   Front silkscreen also marks where each of the 5 real display modules
   actually sits (user: "where are the screens?") — the GC9A01/ST7701S
   glass isn't a PCB footprint (it's off-board, plugged into a small
   edge connector via FPC), so nothing round showed up in a render by
   default. A real circle at each display's position, sized from its
   own datasheet Active Area spec (32.4mm aux gauges, 53.28mm speedo),
   is a genuine mechanical reference for checking alignment against the
   reprinted faceplate, not just decoration.

   Back silkscreen carries an original tachometer-face design (0-8
   sweep, redline arc, resting needle, "x1000 RPM" caption) plus a
   CLUSTER wordmark — replacing the reused sibling-board logo per user
   request ("make it look cool") — drawn directly as KiCad vector
   primitives, not traced from any existing artwork.

   `kicad-cli pcb drc` is clean except real, documented, expected
   findings: the same benign `lib_footprint_mismatch` category every
   sibling board's finished PCB carries, plus silk-clearance findings
   from the screen-outline circles (deliberately bigger than their own
   connector, by design — the real glass overhangs it).

   **6 real M3 mounting/standoff holes added** (4 corners + 2 along the
   top edge) — a board this long and thin needs more than 2 support
   points to avoid real flex/vibration in a dash-mounted automotive
   environment. Adding them shrank the tach-face artwork's own safe
   drawing area, which surfaced two more real bugs, both fixed: the
   first attempt placed the 2 extra holes at naive 1/3 and 2/3
   board-width fractions and landed directly on real components (fixed
   by using the actual empty gaps between core zones instead of a
   guessed position), and the gauge face's internal tick/number/caption
   sizes were tuned for its original ~42mm radius and didn't shrink
   when the real safe area forced a smaller radius, causing real
   overlapping numbers (fixed by scaling every internal offset and text
   size proportionally to the actual radius).

   **Not done yet:** a real board-outline shape (currently a plain
   rectangle — the real housing has a scalloped/contoured profile, not
   a rectangle), and BOM.

4. **PCB routing: done 2026-09-23, 252/252 nets, DRC-clean.**
   `route_board.py` (new this session) follows the same real 4-step
   pipeline every sibling board's own routing uses: export a Specctra
   `.dsn` via `pcbnew.ExportSpecctraDSN` (KiCad's own bundled Python,
   not a reimplementation), run FreeRouting 2.2.4 headless, import the
   resulting `.ses` via `pcbnew.ImportSpecctraSES`, then two purely
   additive post-route passes — widen `VIN_PROT` (the harness's real
   2A-fused input, the only trunk-current net on this board; no motor
   phases here unlike `thermo-pcb`) from its 0.2mm routing width back
   up to 0.6mm wherever room allows, then pour + fill GND (`In1.Cu`)
   and `+3V3` (`In2.Cu`) zones.

   FreeRouting is stochastic (randomized restarts internally, and its
   own RNG behavior tracks the exact board/DSN content, so even a
   cosmetic regenerate reshuffles the outcome). First real cycle
   converged 0 unrouted outright (22 passes, ~110s). A later cycle (on
   a board regenerated to fix the page-size bug below) landed 251/252,
   with `AUX_DC3` (`U9` pin 13 → `U1` pin 24) stuck across 6 retries —
   real autorouter congestion around this board's own 0.5mm-pitch
   parts (`U1` S32K144 LQFP-64, `U2` LMR33630-Q1 VQFN, `U11` BT817AQ
   QFN-64, plus the 5 0.5mm-pitch FPC display connectors), same class
   of outcome `thermo-pcb`'s own routing history shows. Regenerating
   and re-routing once more (no code change, just a fresh DSN export)
   converged fully again: **252/252, 0 unrouted.** Board is genuinely
   done, no hand-routing needed.

   A real bug was found and fixed while verifying the routed result,
   not by DRC (DRC has no opinion on drawing-sheet size): `build_pcb.py`
   computed `BOARD_OFFSET_X/Y` as if the board sat on an A2 (594x420mm)
   page, but never actually told kiutils' `Board` object that — it
   silently kept kiutils' own A4 default, so the *drawn* page frame
   didn't match where the board's own content was actually placed
   (harmless for fab, since Edge.Cuts is what matters there, but
   `kicad-cli pcb export svg` rendered the 447mm board hanging off the
   edge of an A4 sheet). Fixed with one line
   (`board.paper.paperSize = "A2"`) once `PAGE_W`/`PAGE_H` are known;
   caught by actually looking at a rendered SVG layer plot while
   confirming the routing worked, not by any automated check — DRC and
   the script's own self-checks were both clean before and after.

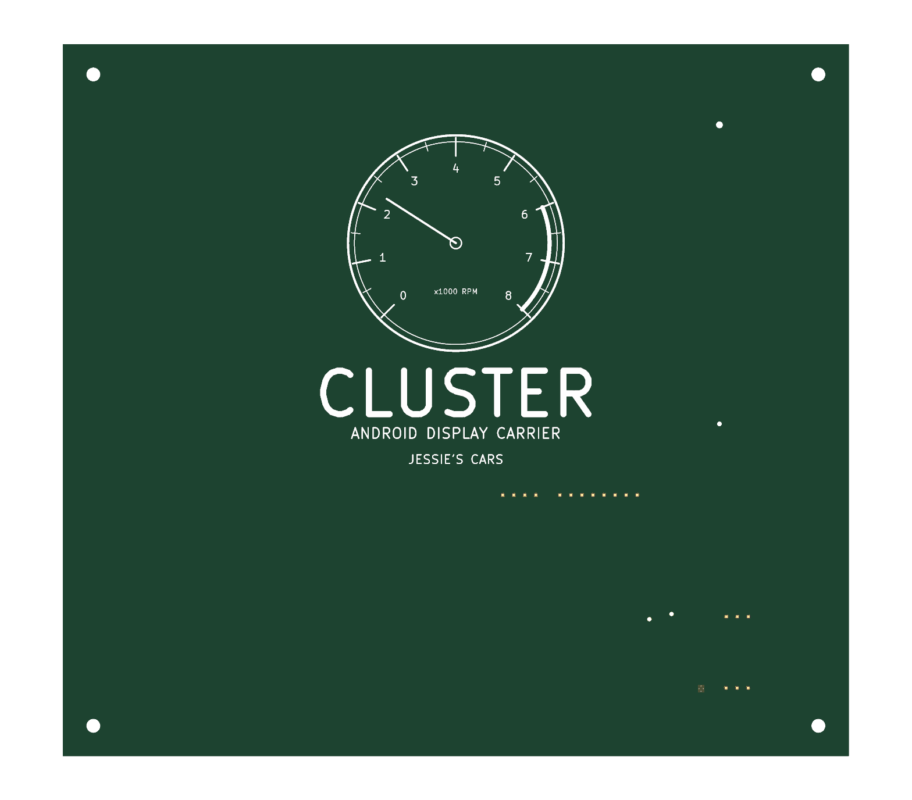
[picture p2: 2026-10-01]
display/ClusterDisplay_back.png

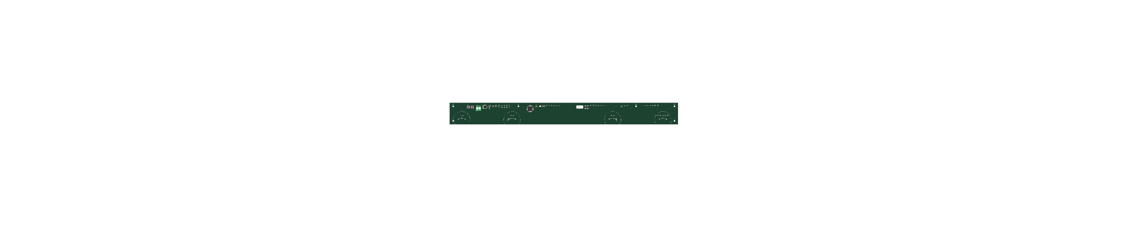
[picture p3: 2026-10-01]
gauges/ClusterGauges_front.png

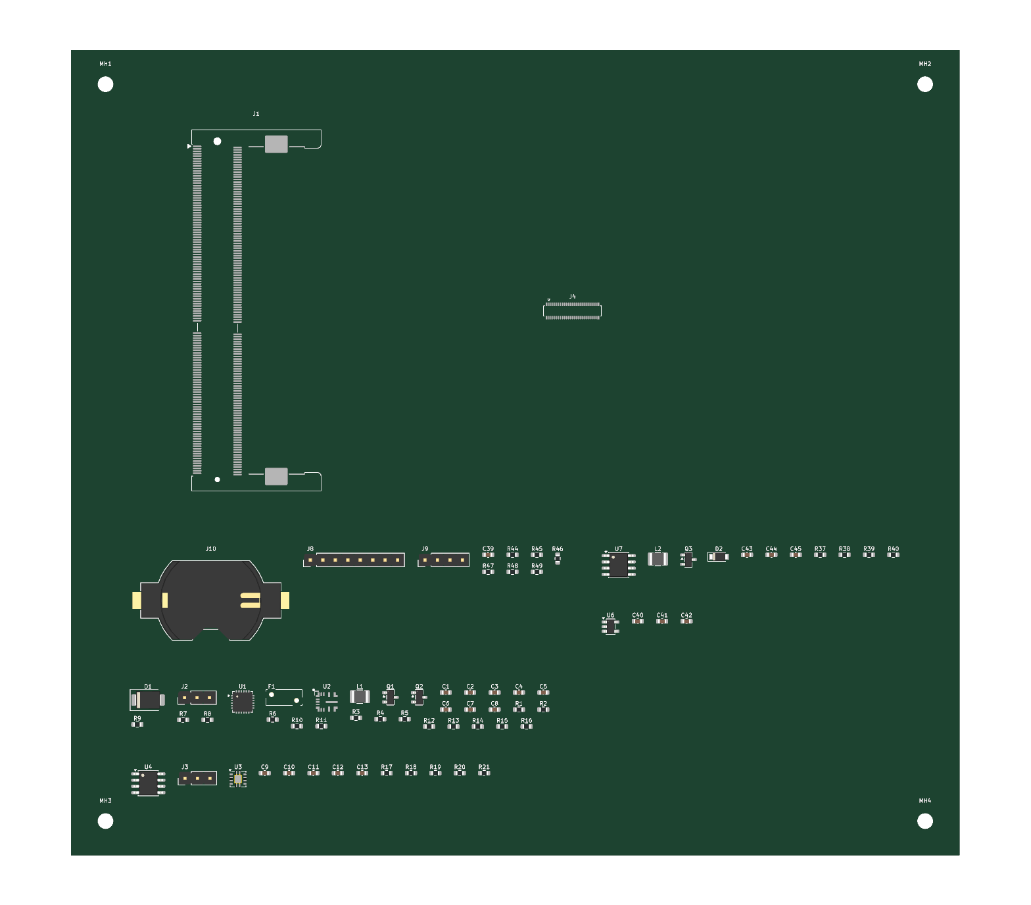
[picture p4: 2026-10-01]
display/ClusterDisplay_front.png

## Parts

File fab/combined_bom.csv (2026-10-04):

Manufacturer Part Number | Manufacturer | Qty display (per board) | Qty gauges (per board) | Description | Status
(momentary push switch - part not chosen yet) | (not yet specified) | 1 | 0 | The dial's click: a normally-open momentary switch wired to J11 pins 3 and 4 (the PSC-360 has no push action). Any panel-mount automotive switch works; contact current is microamps | NEEDS PART SELECTION
(no part - PCB footprint only) | - | 2 | 0 | 3-pad OPEN solder jumper (KiCad SolderJumper-3_P1.3mm_Open_RoundedPad1.0x1.5mm); bridged with a solder blob after verifying the panel's +/-6.5V pin polarity - see JP1/JP2 in build_schematic.py | ok
0297002 | Littelfuse | 0 | 1 | 2A MINI blade fuse element (main 12V input) - same real element ecu-pcb's own BOM already cites | ok
0297005.WXNV | Littelfuse | 1 | 0 | 5A MINI blade fuse element, 32V, 1kA interrupt rating at 32V, -40..+125C (one per board; plugs into the F1 holder) | ok
1058 | Keystone Electronics | 1 | 0 | 20mm coin cell (2032) holder, real unambiguous Keystone part number - same real numbering convention as this family's own Keystone 3568 fuse holder, identified from the real footprint name rather than an independent datasheet citation in build_schematic.py's own comments | ok
22-27-2021 | Molex | 0 | 2 | 2-circuit KK 254 (2.54mm) vertical header, tach input (signal + ground), ECU/coil-driver tach output; coil-negative use on a points ignition is not validated | ok
22-27-2031 | Molex | 1 | 1 | 3-circuit KK 254 (2.54mm) vertical header, board side of the CAN tap (CANH / CANL / GND), 4A / 250V per contact - same KK 254 family gauges/'s J7 uses. This is the display<->gauges<->ECU CAN link. Harness end: sealed Deutsch DTM06-3S (TE) pigtail | ok
22-27-2041 | Molex | 1 | 0 | 4-circuit KK 254 (2.54mm) vertical header for the rotary dial: sensor 5V (switched), sensor signal, ground, click switch. Same KK 254 family as J3 (22-27-2031); mating housing and crimps are separate Molex KK 254 parts | ok
22-27-2051 | Molex | 0 | 1 | 5-position KK 254 (2.54mm) header, board side of the CAN0+sender pigtail | ok
22-27-2081 | Molex | 0 | 1 | 8-circuit KK 254 (2.54mm) vertical header: six 12 V-active indicator-lamp inputs (left turn, right turn, high beam, brake, alternator, oil), ground, and the dash-dimmer feed (instrument-lamp rheostat output); mating housing and crimps are separate Molex KK 254 parts | ok
2309409-2 | TE Connectivity | 1 | 0 | 260-position DDR4 SODIMM socket, 5.2mm stack - the socket Toradex recommends in datasheet section 6.5.1 (docs.toradex.com/200007-verdin_imx95_datasheet.pdf), matching this board's SODIMM-260_DDR4_H4.0-5.2 footprint. The Verdin SoM that plugs into it is its own line under Companion parts (review 2026-10-03: the two were one line) | ok
3568 | Keystone Electronics | 1 | 1 | Mini blade fuse holder, PCB mount - same real holder gauges/ uses. REVIEW FIX 2026-10-03: replaces the Bourns MF-RG500 PTC (16V max, -40..+85C, not rated for jump start or load dump). The 5A fuse element is the next line | ok
ABM8AIG-8.000MHZ-12-2Z-T3 | Abracon | 0 | 1 | 8 MHz 12 pF crystal 3.2 x 2.5 mm, +/-20 ppm, AEC-Q200 [PATTERN: confirm this exact part number in the distributor cart] | PATTERN: confirm in cart
AC0603FR-07100KL | Yageo | 10 | 2 | Resistor 100k 1% 0603 thick film, AEC-Q200 [PATTERN: confirm this exact part number in the distributor cart] | PATTERN: confirm in cart
AC0603FR-07100RL | Yageo | 1 | 1 | Resistor 100R 1% 0603 thick film, AEC-Q200 [PATTERN: confirm this exact part number in the distributor cart] | PATTERN: confirm in cart
AC0603FR-0710K2L | Yageo | 1 | 0 | Resistor 10k2 1% 0603 thick film, AEC-Q200 [PATTERN: confirm this exact part number in the distributor cart] | PATTERN: confirm in cart
AC0603FR-0710KL | Yageo | 9 | 5 | Resistor 10k 1% 0603 thick film, AEC-Q200 [PATTERN: confirm this exact part number in the distributor cart] | PATTERN: confirm in cart
AC0603FR-0711K5L | Yageo | 1 | 1 | Resistor 11k5 1% 0603 thick film, AEC-Q200 [PATTERN: confirm this exact part number in the distributor cart] | PATTERN: confirm in cart
AC0603FR-07120RL | Yageo | 0 | 4 | Resistor 120R 1% 0603 thick film, AEC-Q200 [PATTERN: confirm this exact part number in the distributor cart] | PATTERN: confirm in cart
AC0603FR-07124KL | Yageo | 1 | 0 | Resistor 124k 1% 0603 thick film, AEC-Q200 [PATTERN: confirm this exact part number in the distributor cart] | PATTERN: confirm in cart
AC0603FR-07130KL | Yageo | 1 | 0 | Resistor 130k 1% 0603 thick film, AEC-Q200 [PATTERN: confirm this exact part number in the distributor cart] | PATTERN: confirm in cart
AC0603FR-0715KL | Yageo | 0 | 8 | Resistor 15k 1% 0603 thick film, AEC-Q200 [PATTERN: confirm this exact part number in the distributor cart] | PATTERN: confirm in cart
AC0603FR-071KL | Yageo | 2 | 6 | Resistor 1k 1% 0603 thick film, AEC-Q200 [PATTERN: confirm this exact part number in the distributor cart] | PATTERN: confirm in cart
AC0603FR-071R1L | Yageo | 1 | 0 | Resistor 1R1 1% 0603 thick film, AEC-Q200 [PATTERN: confirm this exact part number in the distributor cart] | PATTERN: confirm in cart
AC0603FR-0722K1L | Yageo | 1 | 0 | Resistor 22k1 1% 0603 thick film, AEC-Q200 [PATTERN: confirm this exact part number in the distributor cart] | PATTERN: confirm in cart
AC0603FR-0722KL | Yageo | 0 | 1 | Resistor 22k 1% 0603 thick film, AEC-Q200 [PATTERN: confirm this exact part number in the distributor cart] | PATTERN: confirm in cart
AC0603FR-0724K9L | Yageo | 2 | 0 | Resistor 24k9 1% 0603 thick film, AEC-Q200 [PATTERN: confirm this exact part number in the distributor cart] | PATTERN: confirm in cart
AC0603FR-0727KL | Yageo | 0 | 1 | Resistor 27k 1% 0603 thick film, AEC-Q200 [PATTERN: confirm this exact part number in the distributor cart] | PATTERN: confirm in cart
AC0603FR-072K05L | Yageo | 1 | 1 | Resistor 2k05 1% 0603 thick film, AEC-Q200 [PATTERN: confirm this exact part number in the distributor cart] | PATTERN: confirm in cart
AC0603FR-072K49L | Yageo | 0 | 1 | Resistor 2k49 1% 0603 thick film, AEC-Q200 [PATTERN: confirm this exact part number in the distributor cart] | PATTERN: confirm in cart
AC0603FR-0733KL | Yageo | 1 | 7 | Resistor 33k 1% 0603 thick film, AEC-Q200 [PATTERN: confirm this exact part number in the distributor cart] | PATTERN: confirm in cart
AC0603FR-0747KL | Yageo | 1 | 0 | Resistor 47k 1% 0603 thick film, AEC-Q200 [PATTERN: confirm this exact part number in the distributor cart] | PATTERN: confirm in cart
AC0603FR-0749K9L | Yageo | 0 | 1 | Resistor 49k9 1% 0603 thick film, AEC-Q200 [PATTERN: confirm this exact part number in the distributor cart] | PATTERN: confirm in cart
AC0603FR-0749R9L | Yageo | 1 | 1 | Resistor 49R9 1% 0603 thick film, AEC-Q200 [PATTERN: confirm this exact part number in the distributor cart] | PATTERN: confirm in cart
AC0603FR-074K7L | Yageo | 0 | 8 | Resistor 4k7 1% 0603 thick film, AEC-Q200 [PATTERN: confirm this exact part number in the distributor cart] [DNP: not fitted by default; the pads stay on the board for the option named in the schematic value (CAN0 end-node termination, ground-switched lamp pull-up, open-collector tach pull-up)] | DNP: do not populate
AC0603FR-07536KL | Yageo | 1 | 0 | Resistor 536k 1% 0603 thick film, AEC-Q200 [PATTERN: confirm this exact part number in the distributor cart] | PATTERN: confirm in cart
AC0603FR-07562KL | Yageo | 1 | 0 | Resistor 562k 1% 0603 thick film, AEC-Q200 [PATTERN: confirm this exact part number in the distributor cart] | PATTERN: confirm in cart
AC0603FR-0756KL | Yageo | 1 | 1 | Resistor 56k 1% 0603 thick film, AEC-Q200 [PATTERN: confirm this exact part number in the distributor cart] | PATTERN: confirm in cart
AC0603FR-0760K4L | Yageo | 1 | 0 | Resistor 60k4 1% 0603 thick film, AEC-Q200 [PATTERN: confirm this exact part number in the distributor cart] | PATTERN: confirm in cart
AC0603FR-0760RL | Yageo | 2 | 4 | Resistor 60R 1% 0603 thick film, AEC-Q200 [PATTERN: confirm this exact part number in the distributor cart] | PATTERN: confirm in cart
AC0603FR-076K04L | Yageo | 1 | 0 | Resistor 6k04 1% 0603 thick film, AEC-Q200 [PATTERN: confirm this exact part number in the distributor cart] | PATTERN: confirm in cart
AC0603FR-076K8L | Yageo | 0 | 1 | Resistor 6k8 1% 0603 thick film, AEC-Q200 [PATTERN: confirm this exact part number in the distributor cart] | PATTERN: confirm in cart
AC0603FR-0780K6L | Yageo | 0 | 1 | Resistor 80k6 1% 0603 thick film, AEC-Q200 [PATTERN: confirm this exact part number in the distributor cart] | PATTERN: confirm in cart
AC0603JR-070RL | Yageo | 1 | 0 | 0 ohm jumper 0603, AEC-Q200 [PATTERN: confirm this exact part number in the distributor cart] | PATTERN: confirm in cart
AC1206FR-0718KL | Yageo | 0 | 2 | Resistor 18k 1% 1206 thick film, 200 V, AEC-Q200 [PATTERN: confirm this exact part number in the distributor cart] | PATTERN: confirm in cart
BAV99-Q (confirm reel suffix at order time) | Nexperia | 3 | 14 | Dual series high-speed switching diode, SOT-23, clamps the ignition-wake gate node to GND and +5V (pin 3 signal, pin 1 GND, pin 2 +5V; datasheet Rev. 8) | ok
BLM18PG221SH1D | Murata | 0 | 1 | 220 ohm @100 MHz ferrite bead, 1.4 A, AEC-Q200 | ok
DTM06-3S | TE Connectivity (Deutsch DTM series) | 0 | 1 | 3-position sealed harness pigtail connector, 12V input + GND + ignition - mates with J1's own board-side terminal block (rev B: was 2-position before the ignition wire was added) | ok
DTM06-5S | TE Connectivity (Deutsch DTM series) | 0 | 1 | 5-position sealed harness pigtail connector: CAN0_H/L + 3x sender input - mates with J7's own board-side header | ok
EEH-ZA1V101P | Panasonic | 1 | 0 | Capacitor, 100 uF 35 V hybrid polymer, 8 x 10.2 mm, AEC-Q200 | ok
F32Q-1A7H1-11018 | Amphenol FCI | 0 | 4 | 18-position 0.5mm FPC connector, right-angle ZIF, bottom contact, one per GC9A01 module [PATTERN: confirm this exact part number in the distributor cart] | PATTERN: confirm in cart
FH26-39S-0.3SHW(99) | Hirose | 1 | 0 | 39-position 0.3mm-pitch FPC connector for the TST040HDBC-42's 39-pin FPC. The panel datasheet does NOT name a connector: 0.3mm pitch is inferred from the FPC's 12mm width across 39 pins, and FH26 is bottom-contact - specify the FPC's exposed-pad side when ordering from TSD. Hirose lists the (05) variant obsolete and FH26W-39S-0.3SHW(60) as current: confirm its land pattern against the bundled FH26 footprint before ordering | ok
FS32K144HAT0MLHT | NXP | 0 | 1 | S32K144 Arm Cortex-M4F, 80 MHz (112 MHz HSRUN), 512 KB flash, CAN FD, LQFP-64 (suffix MLH = 64-LQFP; MLL would be the 100-pin part), -40..125 C, tape and reel; pin-mux verified against NXP's S32K1xx Reference Manual. Orderable part number as listed by Newark, Mouser and TrustedParts (checked 2026-10-04); confirm the suffix on the NXP part page when ordering | ok
GCJ31CC71H475KA01L | Murata | 3 | 0 | Capacitor, 4.7 uF X7R 50 V, AEC-Q200 | ok
GCM1885C1H120JA16D | Murata | 1 | 0 | Capacitor, 12 pF C0G 50 V, AEC-Q200 | ok
GCM1885C1H150JA16D | Murata | 1 | 0 | Capacitor, 15 pF C0G 50 V, AEC-Q200 [PATTERN: confirm this exact part number in the distributor cart] | PATTERN: confirm in cart
GCM1885C1H180JA16D | Murata | 0 | 2 | Capacitor, 18 pF C0G 50 V, AEC-Q200 | ok
GCM1885C1H220JA16D | Murata | 1 | 0 | Capacitor, 22 pF C0G 50 V (Murata marks it NRND; still orderable, swap if unavailable), AEC-Q200 | ok
GCM188R71C105KA64D | Murata | 3 | 3 | Capacitor, 1 uF X7R 16 V, AEC-Q200 | ok
GCM188R71H102KA37D | Murata | 0 | 1 | Capacitor, 1 nF X7R 50 V, AEC-Q200 | ok
GCM188R71H103KA37D | Murata | 2 | 7 | Capacitor, 10 nF X7R 50 V, AEC-Q200 | ok
GCM188R71H104KA57D | Murata | 12 | 20 | Capacitor, 100 nF X7R 50 V, AEC-Q200 | ok
GCM188R71H222KA37D | Murata | 0 | 1 | Capacitor, 2.2 nF X7R 50 V, AEC-Q200 [PATTERN: confirm this exact part number in the distributor cart] | PATTERN: confirm in cart
GCM188R71H224KA64D | Murata | 2 | 1 | Capacitor, 220 nF X7R 50 V, AEC-Q200 | ok
GCM188R71H472KA37D | Murata | 2 | 2 | Capacitor, 4.7 nF X7R 50 V, AEC-Q200 | ok
GCM21BR71A106KE22L | Murata | 3 | 0 | Capacitor, 10 uF X7R 10 V, AEC-Q200 | ok
GCM21BR71C475KA73L | Murata | 2 | 0 | Capacitor, 4.7 uF X7R 16 V, AEC-Q200 | ok
GCM31CR71A226KE02L | Murata | 5 | 2 | Capacitor, 22 uF X7R 10 V, AEC-Q200 | ok
GCM32EC71H106KA03L | Murata | 0 | 1 | Capacitor, 10 uF X7S 50 V, AEC-Q200 | ok
KRL3216E-C-R002-G-T5 | Susumu | 1 | 0 | 2 mohm 2% 1206 current sense, AEC-Q200 | ok
KRL3216E-M-R005-F-T5 | Susumu | 0 | 1 | 5 mohm 1% 1206 current sense, AEC-Q200 (seen on a distributor listing; confirm series suffix against Susumu's datasheet at order time) [PATTERN: confirm this exact part number in the distributor cart] | PATTERN: confirm in cart
LM61460AASQRJRRQ1 | TI | 1 | 0 | Automotive 3-36V 6A low-EMI synchronous buck, main +5V rail, VQFN-HR-14 RJR (datasheet SNVSB70F). LM61460 is a FAMILY of three adjustable variants: AAS (auto light-load mode + spread spectrum, chosen), AAN (auto, no spread spectrum), AFS (forced-PWM + spread spectrum). AAS was picked for EMI; use AFS if PFM ripple at light load is a problem. Not yet bench-verified | ok
LM74930QRGERQ1 | TI | 1 | 1 | Automotive ideal-diode surge stopper w/ circuit breaker + OV clamp, VQFN-24 RGE (datasheet SNOSDF6); TI lists it Active/Production | ok
LMR33630BRNXRQ1 | TI | 0 | 1 | 3A synchronous buck regulator, +5V rail | ok
MKDS 1,5/ 3-5,08 (1715734) | Phoenix Contact | 1 | 1 | 3-position 5.08mm pluggable-style screw terminal block, board side of the car harness power input (VBAT / GND / IGN); 17.5A / 400V nominal - same MKDS 5.08 family gauges/'s J1 uses. Harness end: sealed Deutsch DTM06-3S (TE) pigtail, as on gauges/ | ok
PMEG6010ELRX | Nexperia | 3 | 0 | Boost rectifier Schottky, 60V/1A, SOD-123W | ok
PMV37ENEA | Nexperia | 0 | 1 | N-MOSFET, 12V-rail reverse-protection gate switch / shared backlight low-side switch | ok
PMV55ENEAR | Nexperia | 3 | 2 | 60V N-ch MOSFET, VGS +-20V, 3.1A, SOT-23 - back-to-back ideal-diode/pass FET pair (orderable suffix R = reel; 12NC 934068714215) | ok
PSC360G2-F1A-C0000-ERA360-05K | Amphenol Piher | 1 | 0 | Contactless Hall-effect end-of-shaft rotary position sensor, endless 360-degree rotation with no dead band, 12-bit, 5V +/-10% supply, ratiometric ANALOG output (not PWM/CAN/SPI), 50 million cycles, -40..+125C, fly leads (brown 5V, blue ground, black signal). Use the panel-mount PSC-360U version (3/8"-32 thread, 6.35mm shaft) for a dash hole. Configure: single output, analog, 5V supply, electrical angle 360 degrees, -40..125C. NOTE its 'switch output' is an angle threshold, not a click. This stocked part number (Newark/DigiKey list it) is the flange-mount G2 version: single analog output, 360-degree range, 5V, -40..125C - good for the prototype. A panel-mount PSC-360U ordering code is not confirmed; ask Piher. Piher's web page may describe push-button versions: the datasheet only shows an angle-threshold switch output, so ask Piher before relying on one | NEEDS PART SELECTION
RFA401280B-AYW-DNF1 | Raystar Optronics | 0 | 4 | 1.28in 240x240 round GC9A01 TFT module, SPI, with PCAP touch (touch unused), 18-pin 0.5mm FPC tail, active area 32.4mm. ORDER DIRECT FROM RAYSTAR (salescontact@raystar-optronics.com): the product page lists no price or stock. Ask for the FPC contact fingers on the side that suits the bottom-contact Amphenol connector | ok
SMCJ33A (multi-source) | Littelfuse / onsemi / Vishay (industry-standard P/N) | 1 | 1 | SMC-package TVS diode, 33V standoff, 12V-rail transient protection - not pinned to one vendor, real industry-standard part number, same real part gauges/'s own D1 already uses | ok
TC2030-IDC-NL | Tag-Connect | 0 | 1 | SWD programming/debug connector, 2x3 1.27mm, no-legs cable version | ok
TCAN1044VDRQ1 | TI | 1 | 1 | Automotive CAN FD transceiver w/ 1.8V I/O support (V variant is load-bearing - see parts.py), SOIC-8 D (datasheet SLLSF17D) | ok
TJA1043T/1J | NXP | 0 | 1 | High-speed CAN transceiver with wake, real wiring reused verbatim from ecu-pcb | ok
TLV73333PQDBVRQ1 | TI | 0 | 1 | 300mA LDO, +3.3V rail | ok
TLV76701QWDRBRQ1 | TI | 1 | 0 | Automotive 16V/1A adjustable LDO, +1V8 Verdin I/O rail, VSON-8 DRB with wettable flanks (datasheet SBVS381A); 01 = adjustable, QW = wettable-flank automotive | ok
TPS22918TDBVRQ1 | TI | 1 | 0 | Automotive 1-5.5V 2A load switch, SOT-23-6, switches the rotary dial sensor's 5V off in sleep (ON driven by the Verdin's CTRL_SLEEP_MOCI#; datasheet SLVSCZ8B); TI lists it Active | ok
TPS61165TDBVRQ1 | TI | 1 | 0 | Automotive boost white-LED driver, panel backlight 15V/180mA from +5V with PWM dimming, SOT-23-6 DBV (datasheet SLVSB73B); TI lists the family Active. Orderable suffix taken from a TI E2E thread and a datasheet listing - confirm on TI's store | ok
TPS65131TRGERQ1 | TI | 1 | 0 | Automotive dual-output boost + inverting LCD bias supply, panel +6.5V/-6.5V analog rails from +5V, VQFN-24 RGE with wettable flanks (datasheet SLVSBB2F); TI lists it Active | ok
TSW-103-07-G-S | Samtec | 1 | 0 | 1x3 0.100in gold-finish pin header, A55 console UART_3 (1.8 V logic: use a 1.8 V USB-serial adapter or a level shifter) - bench and service use only | ok
TSW-104-07-G-S | Samtec | 1 | 0 | 1x4 0.100in gold-finish pin header, power/recovery/reset buttons - bench and service use only, not part of the vehicle harness | ok
TSW-105-07-G-S | Samtec | 1 | 0 | 1x5 0.100in gold-finish pin header, USB_1 (VBUS, D-, D+, ID, GND) for flashing/adb bring-up - bench use only, keep the cable short (USB 2.0 high speed over an uncontrolled header) | ok
TSW-108-07-G-S | Samtec | 1 | 0 | 1x8 0.100in gold-finish pin header, JTAG/debug - bench and service use only, not part of the vehicle harness | ok
Team Source Display TST040HDBC-42 | Team Source Display (TSD) | 1 | 0 | 4.0in 720x720 round IPS, native MIPI-DSI (3 lanes), ICNL9707 driver built into the module, 800 cd/m2, -30..+80C, 101.52mm active circle - datasheet V1.0 (2023-06-29) read in full; connects via J4 above, not its own BOM line. Datasheet table and drawing DISAGREE on which FPC pins carry +6.5V vs -6.5V - resolve with TSD before bridging JP1/JP2. Order the FPC with the exposed-pad side matching J4's bottom-contact. ORDER FROM TSD (not a stocked distributor part): request the FPC with contact fingers matching J4 (Hirose FH26 is bottom-contact) and ask the questions in docs/rfq-drafts.md first | ok
Verdin iMX95 Hexa 8GB WB IT (Toradex product no. 0089) | Toradex | 1 | 0 | The SoM that plugs into J1 (docs.toradex.com/200007-verdin_imx95_datasheet.pdf). Toradex product no. 0089 per developer.toradex.com (checked 2026-09-30): V1.0A is end-of-life, V1.0B moved to B0 silicon, V1.1A fixed errata HAR-12581, and V1.1B (Q3 2026) moved to mass-production SoC and PMIC - order the latest revision. Also listed on Mouser | ok
XAL4030-472MEC | Coilcraft | 2 | 0 | 4.7uH shielded molded power inductor, Isat 4.6A, DCR 40mR typ, 4x4x3mm (datasheet Document 806-1; trailing C = 7in reel ordering code) | ok
XAL4040-103MEC | Coilcraft | 1 | 0 | 10uH shielded molded power inductor, Isat 3.0A, DCR 84mR typ, 4x4x4mm (datasheet Document 806-1; trailing C = 7in reel ordering code) | ok
XAL5050-103MEC | Coilcraft | 0 | 1 | 10uH shielded molded power inductor, Isat 4.9A, DCR 41mR typ, 5x5x5mm, AEC-Q200 - meets the LMR33630-Q1 datasheet's rule that Isat not be below the 4.1A low-side limit (datasheet Document 806-1 family; trailing C = 7in reel ordering code) | ok
XEL5030-102MEC | Coilcraft | 1 | 0 | 1uH shielded molded power inductor for the LM61460-Q1 5V buck at 2.1MHz: Isat 16.9A vs the 11.5A max high-side current limit, DCR 7mR typ, 5.5x5.3x3.1mm, AEC-Q200; the part the LM61460-Q1 datasheet's Table 10-5 used for 5V/2.1MHz (Coilcraft Document 1412-2; trailing C = 7in reel ordering code) | ok

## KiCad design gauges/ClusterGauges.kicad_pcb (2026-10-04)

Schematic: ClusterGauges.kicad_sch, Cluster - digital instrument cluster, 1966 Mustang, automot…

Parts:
C1: 10uF 50V X7R CIN (AEC-Q200); C_1210_3225Metric
C2, C45: 22uF 10V X7R COUT (AEC-Q200); C_1206_3216Metric
C3: 1uF X7R (AEC-Q200); C_0603_1608Metric
C4, C5: 18pF (AEC-Q200); C_0603_1608Metric
C6, C7: 100nF (AEC-Q200); C_0603_1608Metric
C8: 1uF (AEC-Q200); C_0603_1608Metric
C11: 100nF BOOT cap (AEC-Q200); C_0603_1608Metric
C12: 1uF VCC decouple (AEC-Q200); C_0603_1608Metric
C13, C40: 100nF VCC decouple (AEC-Q200); C_0603_1608Metric
C14, C41: 100nF VIO decouple (AEC-Q200); C_0603_1608Metric
C15: 100nF VBAT decouple (AEC-Q200); C_0603_1608Metric
C16, C42: 4.7nF SPLIT stabilization (AEC-Q200); C_0603_1608Metric
C17, C18, C19, C20: 100nF VCI decouple (AEC-Q200); C_0603_1608Metric
C28: 100nF ADC_FUEL smoothing (AEC-Q200); C_0603_1608Metric
C29: 100nF ADC_OIL smoothing (AEC-Q200); C_0603_1608Metric
C30: 100nF ADC_TEMP smoothing (AEC-Q200); C_0603_1608Metric
C31: 100nF ADC_BATT smoothing (AEC-Q200); C_0603_1608Metric
C43: 1nF input filter (AEC-Q200); C_0603_1608Metric
C44: 10nF input filter (AEC-Q200); C_0603_1608Metric
C46: 220nF 50V CHF at VIN (AEC-Q200); C_0603_1608Metric
C47: 100nF CVS (50V); C_0603_1608Metric
C48: 100nF CCAP (50V); C_0603_1608Metric
C49: 100nF CTMR; C_0603_1608Metric
C50: 10nF input filter, Left turn (AEC-Q200); C_0603_1608Metric
C51: 10nF input filter, Right turn (AEC-Q200); C_0603_1608Metric
C52: 10nF input filter, High beam (AEC-Q200); C_0603_1608Metric
C53: 10nF input filter, Brake / parking brake (AEC-Q20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; C_0603_1608Metric
C54: 10nF input filter, Alternator / charge (AEC-Q200); C_0603_1608Metric
C55: 10nF input filter, Oil pressure (AEC-Q200); C_0603_1608Metric
C56: 2.2nF input filter, tach (AEC-Q200); C_0603_1608Metric
C57: 100nF input filter, dash dimmer (AEC-Q200); C_0603_1608Metric
D1: SMCJ33A automotive (AEC-Q101) on the fused input,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; D_SMC
D10, D11: BAV99-Q input clamp (AEC-Q101); SOT-23
D12: BAV99-Q fuel input clamp (AEC-Q101); SOT-23
D13: BAV99-Q oil input clamp (AEC-Q101); SOT-23
D14: BAV99-Q temp input clamp (AEC-Q101); SOT-23
D15: BAV99-Q battery divider clamp (AEC-Q101); SOT-23
D16: BAV99-Q input clamp, Left turn (AEC-Q101); SOT-23
D17: BAV99-Q input clamp, Right turn (AEC-Q101); SOT-23
D18: BAV99-Q input clamp, High beam (AEC-Q101); SOT-23
D19: BAV99-Q input clamp, Brake / parking brake (AEC-Q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; SOT-23
D20: BAV99-Q input clamp, Alternator / charge (AEC-Q10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; SOT-23
D21: BAV99-Q input clamp, Oil pressure (AEC-Q101); SOT-23
D22: BAV99-Q input clamp, tach (AEC-Q101); SOT-23
D23: BAV99-Q input clamp, dash dimmer (AEC-Q101); SOT-23
F1: Mini blade holder, 2A Littelfuse 297 fuse (SAE J2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; Fuseholder_Blade_Mini_Keystone_3568
J1: DTM06-3S nickel, 12V input + ignition (sealed); TerminalBlock_Phoenix_MKDS-1,5-3-5.08_1x03_P5.08mm_Horizont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
J2: SWD Tag-Connect; Tag-Connect_TC2030-IDC-NL_2x03_P1.27mm_Vertical
J7: DTM06-5S nickel, CAN0 + 3x sender input (sealed); Molex_KK-254_AE-6410-05A_1x05_P2.54mm_Vertical
J8: KK-254 22-27-2031, private link to display/ J3 (D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; Molex_KK-254_AE-6410-03A_1x03_P2.54mm_Vertical
J9: KK-254 22-27-2021, Hall speed sender (signal + gr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; Molex_KK-254_AE-6410-02A_1x02_P2.54mm_Vertical
J10: KK-254 22-27-2081, indicator lamp inputs (6 x 12 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; Molex_KK-254_AE-6410-08A_1x08_P2.54mm_Vertical
J11: KK-254 22-27-2021, tach input (signal + ground); Molex_KK-254_AE-6410-02A_1x02_P2.54mm_Vertical
L1: 10uH power XAL5050-103ME (AEC-Q200); L_Coilcraft_XAL5050-XXX
L2: ferrite bead (AEC-Q200); L_0603_1608Metric
Q1: PMV55ENEA ideal diode (DGATE); SOT-23
Q2: PMV37ENEA automotive (AEC-Q101) - shared aux-gaug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; SOT-23
Q3: PMV55ENEA pass (HGATE); SOT-23
R1: 10k pull-up (AEC-Q200); R_0603_1608Metric
R2: 10k (AEC-Q200); R_0603_1608Metric
R3: 2.49k (AEC-Q200); R_0603_1608Metric
R4, R5: 60R split termination (AEC-Q200) - DNP unless bus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; R_0603_1608Metric
R6, R7, R8, R9: 120R VLED series (self-calculated for ~15mA at 5V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; R_0603_1608Metric
R10: 100R BL_EN gate resistor (AEC-Q200); R_0603_1608Metric
R11: 10k LPSPI2_SIN pull-down, idle-state definition (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; R_0603_1608Metric
R16: 1k fuel pull-up to +3V3 (11mW at a 10R sender) (A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; R_0603_1608Metric
R17: 1k oil pull-up to +3V3 (AEC-Q200); R_0603_1608Metric
R18: 1k coolant temp pull-up to +3V3 (AEC-Q200); R_0603_1608Metric
R19: 49.9k battery divider top, self-calculated for 9-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; R_0603_1608Metric
R20: 10k battery divider bottom, self-calculated for 9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; R_0603_1608Metric
R40: 10k STB pulldown, normal mode while MCU resets (A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; R_0603_1608Metric
R41, R42: 60R split termination (AEC-Q200); R_0603_1608Metric
R43: 4.7k pull-up to VIN_PROT for open-collector sende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; R_0603_1608Metric
R44: 33k series (AEC-Q200); R_0603_1608Metric
R45: 15k divider bottom (AEC-Q200); R_0603_1608Metric
R46: 56k series (AEC-Q200); R_0603_1608Metric
R47: 27k divider bottom (AEC-Q200); R_0603_1608Metric
R48: 49.9R 1% RSET; R_0603_1608Metric
R49: 5m 1% sense (Susumu KRL3216E-M-R005-F-T5); R_1206_3216Metric
R50: 80.6k 1% RILIM (1.5A breaker); R_0603_1608Metric
R51: 100k OV top; R_0603_1608Metric
R52: 2.05k OV bot (clamp 29.9V); R_0603_1608Metric
R53: 100k UV top; R_0603_1608Metric
R54: 11.5k UV bot (cut-off 5.5V); R_0603_1608Metric
R55: 1k fuel ADC series (AEC-Q200); R_0603_1608Metric
R56: 1k oil ADC series (AEC-Q200); R_0603_1608Metric
R57: 1k temp ADC series (AEC-Q200); R_0603_1608Metric
R58: 33k series, Left turn (AEC-Q200); R_0603_1608Metric
R59: 15k divider bottom, Left turn (AEC-Q200); R_0603_1608Metric
R60: 4.7k pull-up to VIN_PROT, DNP: fit only if the Le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; R_0603_1608Metric
R61: 33k series, Right turn (AEC-Q200); R_0603_1608Metric
R62: 15k divider bottom, Right turn (AEC-Q200); R_0603_1608Metric
R63: 4.7k pull-up to VIN_PROT, DNP: fit only if the Ri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; R_0603_1608Metric
R64: 33k series, High beam (AEC-Q200); R_0603_1608Metric
R65: 15k divider bottom, High beam (AEC-Q200); R_0603_1608Metric
R66: 4.7k pull-up to VIN_PROT, DNP: fit only if the Hi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; R_0603_1608Metric
R67: 33k series, Brake / parking brake (AEC-Q200); R_0603_1608Metric
R68: 15k divider bottom, Brake / parking brake (AEC-Q2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; R_0603_1608Metric
R69: 4.7k pull-up to VIN_PROT, DNP: fit only if the Br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; R_0603_1608Metric
R70: 33k series, Alternator / charge (AEC-Q200); R_0603_1608Metric
R71: 15k divider bottom, Alternator / charge (AEC-Q200); R_0603_1608Metric
R72: 4.7k pull-up to VIN_PROT, DNP: fit only if the Al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; R_0603_1608Metric
R73: 33k series, Oil pressure (AEC-Q200); R_0603_1608Metric
R74: 15k divider bottom, Oil pressure (AEC-Q200); R_0603_1608Metric
R75: 4.7k pull-up to VIN_PROT, DNP: fit only if the Oi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; R_0603_1608Metric
R76, R77: 18k series, tach, 200V (AEC-Q200); R_1206_3216Metric
R78: 15k divider bottom, tach (AEC-Q200); R_0603_1608Metric
R79: 4.7k pull-up to VIN_PROT, DNP: fit only for an op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; R_0603_1608Metric
R80: 22k divider top, dash dimmer (AEC-Q200); R_0603_1608Metric
R81: 6.8k divider bottom, dash dimmer (AEC-Q200); R_0603_1608Metric
U1: NXP S32K144 automotive (AEC-Q100); LQFP-64_10x10mm_P0.5mm
U2: LMR33630-Q1 (AEC-Q100 G1); TI_RNX0012C_VQFN-HR-12_2x3mm_P0.5mm
U3: LM74930-Q1 (AEC-Q100 G1); Texas_RGE0024H_VQFN-24-1EP_4x4mm_P0.5mm_EP2.7x2.7mm
U4: TLV733P-Q1 (AEC-Q100 G1); SOT-23-5
U5: NXP TJA1043T automotive CAN transceiver (AEC-Q100); SOIC-14_3.9x8.7mm_P1.27mm
U6: Raystar RFA401280B-AYW-DNF1 - Fuel level gauge; Amphenol_F32Q-1A7x1-11018_1x18-1MP_P0.5mm_Horizontal
U7: Raystar RFA401280B-AYW-DNF1 - Oil pressure gauge; Amphenol_F32Q-1A7x1-11018_1x18-1MP_P0.5mm_Horizontal
U8: Raystar RFA401280B-AYW-DNF1 - Coolant temp gauge; Amphenol_F32Q-1A7x1-11018_1x18-1MP_P0.5mm_Horizontal
U9: Raystar RFA401280B-AYW-DNF1 - Battery voltage gau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; Amphenol_F32Q-1A7x1-11018_1x18-1MP_P0.5mm_Horizontal
U10: TCAN1044V-Q1 (AEC-Q100 G1); SOIC-8_3.9x4.9mm_P1.27mm
Y1: 8MHz (AEC-Q200); Crystal_SMD_3225-4Pin_3.2x2.5mm

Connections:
+3V3: C3.1, C6.1, C7.1, C14.1, C17.1, C18.1, C19.1, C20.1, C41.1, D10.2 (K2), D11.2 (K2), D12.2 (K2), D13.2 (K2), D14.2 (K2), D15.2 (K2), D16.2 (K2), D17.2 (K2), D18.2 (K2), D19.2 (K2), D20.2 (K2), D21.2 (K2), D22.2 (K2), D23.2 (K2), J2.2 (VCC), L2.1, R1.1, R16.1, R17.1, R18.1, U1.7 (VDD), U1.41 (VDD), U4.5 (OUT), U5.5 (VIO), U6.16 (VCI3V3), U7.16 (VCI3V3), U8.16 (VCI3V3), U9.16 (VCI3V3), U10.5 (VIO)
+5V: C2.1, C13.1, C40.1, C45.1, L1.2, R2.1, R6.1, R7.1, R8.1, R9.1, U4.1 (IN), U4.3 (EN), U5.3 (VCC), U10.3 (VCC)
ADC_BATT: C31.1, D15.3 (CA), R19.2, R20.1, U1.47 (ADC_BATT)
ADC_FUEL: C28.1, D12.3 (CA), R55.2, U1.50 (ADC_FUEL)
ADC_OIL: C29.1, D13.3 (CA), R56.2, U1.49 (ADC_OIL)
ADC_TEMP: C30.1, D14.3 (CA), R57.2, U1.48 (ADC_TEMP)
AUX_CS0: U1.13 (AUX_CS0), U6.10 (CS)
AUX_CS1: U1.14 (AUX_CS1), U7.10 (CS)
AUX_CS2: U1.15 (AUX_CS2), U8.10 (CS)
AUX_CS3: U1.16 (AUX_CS3), U9.10 (CS)
AUX_DC0: U1.17 (AUX_DC0), U6.13 (RS)
AUX_DC1: U1.22 (AUX_DC1), U7.13 (RS)
AUX_DC2: U1.23 (AUX_DC2), U8.13 (RS)
AUX_DC3: U1.24 (AUX_DC3), U9.13 (RS)
AUX_RST: U1.42 (AUX_RST), U6.15 (RESET), U7.15 (RESET), U8.15 (RESET), U9.15 (RESET)
AUX_VLED_RTN: Q2.3 (D), U6.8 (VLED-), U7.8 (VLED-), U8.8 (VLED-), U9.8 (VLED-)
BL_EN: R10.1, U1.39 (BL_EN)
BL_GATE: Q2.1 (G), R10.2
BOOT_CAP: C11.1, U2.4 (BOOT)
CAN0_EN: U1.18 (CAN0_EN), U5.6 (EN)
CAN0_H: J7.1 (CAN0_H), R4.1, U5.13 (CANH)
CAN0_L: J7.2 (CAN0_L), R5.2, U5.12 (CANL)
CAN0_RX: U1.6 (CAN0_RX), U5.4 (RXD)
CAN0_SPLIT: C16.1, R4.2, R5.1, U5.11 (SPLIT)
CAN0_STB_N: U1.19 (CAN0_STB_N), U5.14 (STB_N)
CAN0_TX: U1.5 (CAN0_TX), U5.1 (TXD)
CAN1_H: J8.1 (CAN1_H), R41.1, U10.7 (CANH)
CAN1_L: J8.2 (CAN1_L), R42.2, U10.6 (CANL)
CAN1_RX: U1.52 (CAN1_RX), U10.4 (RXD)
CAN1_SPLIT: C42.1, R41.2, R42.1
CAN1_STB: R40.1, U1.60 (CAN1_STB), U10.8 (STB)
CAN1_TX: U1.51 (CAN1_TX), U10.1 (TXD)
CAP_CP: C48.1, U3.23 (CAP)
COMMON: Q1.2 (S), Q3.2 (S), U3.2 (A), U3.15 (OUT)
CS_PLUS: R48.2, U3.20 (CS+)
DGATE: Q1.1 (G), U3.1 (DGATE)
DIM_ADC: C57.1, D23.3 (CA), R80.2, R81.1, U1.31 (DIM_ADC)
DIM_RAW: J10.8 (DIM_RAW), R80.1
FB: R2.2, R3.1, U2.7 (FB)
HGATE: Q3.1 (G), U3.14 (HGATE)
IGN_SENSE: C44.1, D11.3 (CA), R46.2, R47.1, U1.59 (IGN_SENSE)
ILIM: R50.1, U3.11 (ILIM)
LAMP_ALT: C54.1, D20.3 (CA), R70.2, R71.1, U1.43 (LAMP_ALT)
LAMP_ALT_RAW: J10.5 (LAMP_ALT), R70.1, R72.2
LAMP_BRAKE: C53.1, D19.3 (CA), R67.2, R68.1, U1.38 (LAMP_BRAKE)
LAMP_BRAKE_RAW: J10.4 (LAMP_BRAKE), R67.1, R69.2
LAMP_HIGH_BEAM: C52.1, D18.3 (CA), R64.2, R65.1, U1.37 (LAMP_HIGH_BEAM)
LAMP_HIGH_BEAM_RAW: J10.3 (LAMP_HIGH_BEAM), R64.1, R66.2
LAMP_OIL: C55.1, D21.3 (CA), R73.2, R74.1, U1.44 (LAMP_OIL)
LAMP_OIL_RAW: J10.6 (LAMP_OIL), R73.1, R75.2
LAMP_TURN_L: C50.1, D16.3 (CA), R58.2, R59.1, U1.35 (LAMP_TURN_L)
LAMP_TURN_L_RAW: J10.1 (LAMP_TURN_L), R58.1, R60.2
LAMP_TURN_R: C51.1, D17.3 (CA), R61.2, R62.1, U1.36 (LAMP_TURN_R)
LAMP_TURN_R_RAW: J10.2 (LAMP_TURN_R), R61.1, R63.2
LPSPI2_SCK: U1.29 (LPSPI2_SCK), U6.11 (SCL), U7.11 (SCL), U8.11 (SCL), U9.11 (SCL)
LPSPI2_SIN: R11.1, U1.26 (LPSPI2_SIN)
LPSPI2_SOUT: U1.25 (LPSPI2_SOUT), U6.12 (SDA), U7.12 (SDA), U8.12 (SDA), U9.12 (SDA)
OSC_IN: C4.1, U1.11 (OSC_IN), Y1.1 (OSC_IN), Y1.3 (OSC_IN)
OSC_OUT: C5.1, U1.12 (OSC_OUT), Y1.2 (OSC_OUT), Y1.4 (OSC_OUT)
OV_DIV: R51.2, R52.1, U3.5 (OV), U3.16 (OVCLAMP)
RESET: J2.5 (RST), R1.2, U1.63 (RESET)
SENDER_FUEL: J7.3 (FUEL_SENSE), R16.2, R55.1
SENDER_OIL: J7.4 (OIL_SENSE), R17.2, R56.1
SENDER_TEMP: J7.5 (TEMP_SENSE), R18.2, R57.1
SENSE_OUT: Q3.3 (D), R49.2, U3.19 (CS-)
SPEED_IN: C43.1, D10.3 (CA), R44.2, R45.1, U1.58 (SPEED_IN)
SPEED_RAW: J9.1 (SPEED_SIG), R43.2, R44.1
SW: C11.2, L1.1, U2.3 (NC), U2.12 (SW)
SWCLK: J2.3 (SWCLK), U1.62 (SWCLK)
SWDIO: J2.1 (SWDIO), U1.64 (SWDIO)
SW_SENSE: R51.1, R53.1, U3.3 (SW)
TACH_IN: C56.1, D22.3 (CA), R77.2, R78.1, U1.57 (TACH_IN)
TACH_MID: R76.2, R77.1
TACH_RAW: J11.1 (TACH_SIG), R76.1, R79.2
TMR: C49.1, U3.9 (TMR)
U6_VLED: R6.2, U6.7 (VLED+)
U7_VLED: R7.2, U7.7 (VLED+)
U8_VLED: R8.2, U8.7 (VLED+)
U9_VLED: R9.2, U9.7 (VLED+)
UVLO_DIV: R53.2, R54.1, U3.4 (UVLO)
VCC_INT: C12.1, U2.5 (VCC)
VDDA: C8.1, L2.2, U1.8 (VDDA), U1.9 (VREFH)
VIN: F1.1, J1.1 (VIN)
VIN_FUSED: C47.1, C48.2, D1.1, F1.2, R48.1, R49.1, U3.6 (EN), U3.7 (MODE), U3.22 (VS)
VIN_PROT: C1.1, C15.1, C46.1, Q1.3 (D), R19.1, R43.1, R60.1, R63.1, R66.1, R69.1, R72.1, R75.1, R79.1, U2.2 (VIN), U2.9 (EN), U2.10 (VIN), U3.18 (ISCP), U3.24 (C), U5.10 (VBAT)

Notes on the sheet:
MCU CORE (NXP S32K144, 3.3V LOGIC) - FIXED PINS ONLY
See protocol/ for the message set and the plan for the reasons.
1. Power nets (+5V, +3V3, GND, VIN) use power symbols throughout; signal nets use
carriers to communicate.
REV B: IGNITION SENSE (STOP-mode wake)
3. U1 (S32K144) pin numbers are REAL - fixed pins verified against NXP's Reference
U6-U9 (GC9A01) use Raystar's real RFA401280B-AYW-DNF1 pinout - backlight is a
real strategy thermo-pcb established. Not yet re-confirmed as the right choice
SENSOR ADC FRONT END: FUEL / OIL / TEMP / BATTERY (PLAN STEP 5)
bare LED pair (not a logic pin), driven from +5V with a shared MOSFET switch.
PCB layout/routing/DRC/BOM are separate, not-yet-started next phases.
separate carrier, cluster-pcb/display/ (Verdin iMX95 + SN65DSI85-Q1, running
5. Value fields tag automotive qualification: Q100 G1 = AEC-Q100 Grade 1 (ICs) -
AAOS, driving a larger round panel). CAN0 on THIS board now also carries gauge
curve (README.md), not a shared guess.
data pushed from that Android carrier, not just ecu-pcb traffic and local
drawn wires, with local labels only where pins are legitimately shared.
6. J1 (power) and J7 (CAN0 + 3x sender) both land real Molex KK-254/Phoenix MKDS
programmatically, not by eye. No generic placeholders anywhere.
8. REV B (2026-09-30): gateway architecture. This board is the ONLY node on the car
NOTES:
INPUT PROTECTION: LM74930-Q1 IDEAL DIODE + OV CLAMP + CURRENT LIMIT (review fix 2026-10-03)
Automotive re-architecture - the center speedo (BT817AQ + ST7701S) moved to a
sender readings - a real 3-node bus, per the user's own request for the two
REV C: INDICATOR LAMPS (6 x 12 V-ACTIVE) AND TACH INPUT
for a dash-mounted (not engine-bay) board.
REV B: CAN1 PRIVATE LINK TO display/ (TCAN1044V-Q1)
4. U5 (TJA1043T) reused verbatim from ecu-pcb's own real CAN transceiver circuit.
CAN1 link (U10, J8). Added a Hall speed input (J9) and an ignition input (J1 pin 3).
R16-R20 (sensor dividers) are each sized from the sender's own real resistance
Q101 = AEC-Q101 (discretes) - Q200 = AEC-Q200 (passives).
own embedded IO-signal-table attachment, cross-checked pin-by-pin for collisions
5V BUCK + 3.3V LDO
bus (CAN0, firmware listen-only) and aggregates values for display/ over a private
2. Power stage (F1/Q1/U2/U3/U4 + supporting passives) reused VERBATIM from
7. RE-SCOPED 2026-09-25: this board is the small-gauges half of Cluster's Android
peripheral pins (LPSPI2/FlexCAN0/4xADC/GPIO) verified against the same Manual's
REV B: HALL SPEED INPUT (AutoMeter-type 12 V pulse sender)
4x GC9A01 AUX GAUGES: FUEL / OIL / COOLANT TEMP / BATTERY (PLAN STEP 3)
board-side connectors, sealed DTM06 nickel pigtails on the outboard end - same

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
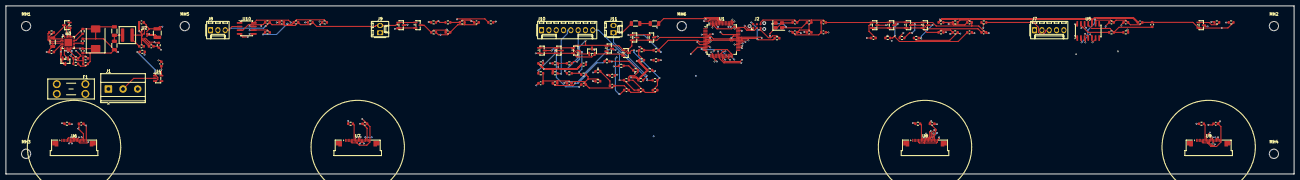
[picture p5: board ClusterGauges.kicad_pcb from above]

Board: 4 copper layers, 447.1 x 58.3 mm, 143 parts (0 on the bottom side), 87 nets.

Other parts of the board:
MH1, MH2, MH3, MH4, MH5, MH6: MountingHole_3.2mm_M3

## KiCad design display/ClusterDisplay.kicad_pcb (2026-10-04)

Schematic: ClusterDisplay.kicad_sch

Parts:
C1: 100u 35V hybrid polymer hold-up (Panasonic EEH-ZA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; CP_Elec_8x10
C2: 100n CVS; C_0603_1608Metric
C3: 100n CCAP; C_0603_1608Metric
C4: 100n CTMR; C_0603_1608Metric
C5: 4.7u CIN VIN1; C_1206_3216Metric
C6: 1u VCC; C_0603_1608Metric
C7: 100n boot; C_0603_1608Metric
C8, C54, C59: 22u COUT; C_1206_3216Metric
C9: 10u CIN; C_0805_2012Metric
C10: 10u COUT; C_0805_2012Metric
C11: 100n VCC; C_0603_1608Metric
C12: 100n VIO; C_0603_1608Metric
C13: 4n7 split; C_0603_1608Metric
C39: 100n; C_0603_1608Metric
C40: 4.7u boost in (AEC-Q200); C_0805_2012Metric
C41: 4.7u inverter in (AEC-Q200); C_0805_2012Metric
C42: 100n VIN filter (AEC-Q200); C_0603_1608Metric
C43: 220n VREF (AEC-Q200); C_0603_1608Metric
C44: 10n CP comp (AEC-Q200); C_0603_1608Metric
C45: 4n7 CN comp (AEC-Q200); C_0603_1608Metric
C46: 22u VPOS out 16V (AEC-Q200); C_1206_3216Metric
C47: 22u VNEG out 16V (AEC-Q200); C_1206_3216Metric
C48: 12p VPOS feed-forward (AEC-Q200); C_0603_1608Metric
C49: 15p VNEG feed-forward (AEC-Q200); C_0603_1608Metric
C50: 10u BL input (AEC-Q200); C_0805_2012Metric
C51: 220n BL COMP (AEC-Q200); C_0603_1608Metric
C52: 4.7u BL output, 50V part (AEC-Q200); C_1206_3216Metric
C53: 10n ignition filter; C_0603_1608Metric
C55: 4.7u CIN VIN2; C_1206_3216Metric
C56: 100n CHF VIN1; C_0603_1608Metric
C57: 100n CHF VIN2; C_0603_1608Metric
C58: 22p CFF; C_0603_1608Metric
C60: 1u dial switch CIN; C_0603_1608Metric
C61: 100n dial signal filter; C_0603_1608Metric
C62: 100n dial click debounce; C_0603_1608Metric
C63: 1u dial 5V filter; C_0603_1608Metric
D1: SMCJ33A; D_SMB
D2, D3, D4: PMEG6010ELRX (AEC-Q101, 60V/1A); Nexperia_CFP3_SOD-123W
D5: BAV99-Q ignition clamp (AEC-Q101); SOT-23
D6: BAV99-Q dial signal clamp (AEC-Q101); SOT-23
D7: BAV99-Q dial click clamp (AEC-Q101); SOT-23
F1: Keystone 3568 holder, 5A Littelfuse 0297005.WXNV 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; Fuseholder_Blade_Mini_Keystone_3568
J1: Verdin iMX95 Hexa 8GB WB IT; SODIMM-260_DDR4_H4.0-5.2_OrientationStd_Socket
J2: Phoenix MKDS 1,5/3-5,08 power in (DTM06-3S pigtai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; TerminalBlock_Phoenix_MKDS-1,5-3-5.08_1x03_P5.08mm_Horizont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
J3: Molex KK-254 22-27-2031 private CAN link to gauge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; Molex_KK-254_AE-6410-03A_1x03_P2.54mm_Vertical
J4: TST040HDBC-42 panel; Hirose_FH26-39S-0.3SHW_2Rows-39Pins-1MP_P0.60mm_Horizontal
J8: Samtec TSW-108-07-G-S JTAG (bench only); PinHeader_1x08_P2.54mm_Vertical
J9: Samtec TSW-104-07-G-S buttons (bench only); PinHeader_1x04_P2.54mm_Vertical
J10: RTC coin cell; BatteryHolder_Keystone_1058_1x2032
J11: Molex KK-254 22-27-2041, rotary dial (PSC-360 + c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; Molex_KK-254_AE-6410-04A_1x04_P2.54mm_Vertical
J12: Samtec TSW-103-07-G-S A55 console UART_3 1.8V (be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; PinHeader_1x03_P2.54mm_Vertical
J13: Samtec TSW-105-07-G-S USB_1 OTG (bench only); PinHeader_1x05_P2.54mm_Vertical
JP1: SJ3 OPEN: bridge 1-2 if datasheet TABLE is right 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; SolderJumper-3_P1.3mm_Open_RoundedPad1.0x1.5mm
JP2: SJ3 OPEN: bridge 2-3 if datasheet TABLE is right 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; SolderJumper-3_P1.3mm_Open_RoundedPad1.0x1.5mm
L1: 1u XEL5030-102ME 2.1MHz; L_Coilcraft_XAL5030-XXX
L2: 4.7u boost (Coilcraft XAL4030-472ME); L_Coilcraft_XAL4030-XXX
L3: 4.7u inverter (Coilcraft XAL4030-472ME); L_Coilcraft_XAL4030-XXX
L4: 10u BL boost (Coilcraft XAL4040-103ME); L_Coilcraft_XAL4040-XXX
Q1: PMV55ENEA (AEC-Q101, 60V/20V VGS) diode; SOT-23
Q2: PMV55ENEA (AEC-Q101, 60V/20V VGS) pass; SOT-23
Q3: PMV55ENEA ignition wake pulldown; SOT-23
R1: 2m 2% sense (Susumu KRL3216E-C-R002-G-T5); R_1206_3216Metric
R2: 49.9R 1% RSET; R_0603_1608Metric
R3: 60.4k RILIM; R_0603_1608Metric
R4: 10k RIMON; R_0603_1608Metric
R5: 100k OV top; R_0603_1608Metric
R6: 2.05k OV bot; R_0603_1608Metric
R7: 100k UV top; R_0603_1608Metric
R8: 11.5k UV bot; R_0603_1608Metric
R9: 0R RBOOT; R_0603_1608Metric
R10: 100k FB top; R_0603_1608Metric
R11: 24.9k FB bot; R_0603_1608Metric
R12: 6.04k RT; R_0603_1608Metric
R13: 100k EN top; R_0603_1608Metric
R14: 24.9k EN bot; R_0603_1608Metric
R15: 100k FLT pu; R_0603_1608Metric
R16: 100k PG pu; R_0603_1608Metric
R17: 124k FB top; R_0603_1608Metric
R18: 100k FB bot; R_0603_1608Metric
R19, R20: 60R term; R_0603_1608Metric
R21: 10k STB pd; R_0603_1608Metric
R37: 100R VIN filter; R_0603_1608Metric
R38: 562k VPOS top R1 (see docstring); R_0603_1608Metric
R39: 130k VPOS bottom R2 (see docstring); R_0603_1608Metric
R40: 536k VNEG top R3 (see docstring); R_0603_1608Metric
R41: 100k VNEG bottom R4 to VREF (see docstring); R_0603_1608Metric
R42: 1.10R LED current sense (0.2V/1.10=182mA); R_0603_1608Metric
R43: 100k bias-enable pulldown; R_0603_1608Metric
R44, R45, R46, R47: 10k pullup; R_0603_1608Metric
R48: 10k JTAG Vref; R_0603_1608Metric
R49: 47k min; R_0603_1608Metric
R50: 100k panel-reset pulldown; R_0603_1608Metric
R51: 56k ignition series; R_0603_1608Metric
R52: 33k ignition divider bottom; R_0603_1608Metric
R53: 10k wake pull-up to +1V8; R_0603_1608Metric
R54: 22.1k dial signal divider top; R_0603_1608Metric
R55: 1k dial signal series; R_0603_1608Metric
R56: 1k dial click series; R_0603_1608Metric
R57: 10k dial click pull-up to +1V8; R_0603_1608Metric
R58: 10.2k dial signal divider bottom; R_0603_1608Metric
U1: LM74930-Q1; Texas_RGE0024H_VQFN-24-1EP_4x4mm_P0.5mm_EP2.7x2.7mm
U2: LM61460-Q1; TI_RJR0014A_VQFN-HR-14_4x3.5mm
U3: TLV767-Q1; Texas_DRB0008A
U4: TCAN1044V-Q1; SOIC-8_3.9x4.9mm_P1.27mm
U6: TPS65131-Q1; HVQFN-24-1EP_4x4mm_P0.5mm_EP2.5x2.5mm
U7: TPS61165-Q1; SOT-23-6
U8: TPS22918-Q1 (AEC-Q100 G2) dial 5V switch; SOT-23-6

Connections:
+1V8: C10.1, C12.1, D6.2 (K2), D7.2 (K2), J4.13 (IOVCC), J4.14 (IOVCC), R17.1, R44.2, R45.2, R46.2, R47.2, R48.2, R53.1, R57.1, U3.1 (OUT), U4.5 (VIO)
+5V: C8.1, C9.1, C11.1, C40.1, C41.1, C50.1, C54.1, C58.1, C59.1, C60.1, D5.2 (K2), J1.251 (VCC), J1.253 (VCC), J1.255 (VCC), J1.257 (VCC), J1.259 (VCC), L1.2, L2.1, L4.1, R10.1, R15.2, R16.2, R37.1, U2.1 (BIAS), U3.8 (IN), U4.3 (VCC), U6.5 (INN1), U6.6 (INN2), U7.1 (VIN), U8.1 (VIN)
+12V_PROT: C1.1, C5.1, C55.1, C56.1, C57.1, Q1.3 (D), R13.1, U1.18 (ISCP), U1.24 (C), U2.8 (VIN1), U2.12 (VIN2)
BL_COMP: C51.1, U7.5 (COMP)
BL_SW: D4.2, L4.2, U7.3 (SW)
BOOT_C: C7.1, R9.2, U2.14 (CBOOT)
BOOT_R: R9.1, U2.13 (RBOOT)
CAN1_H: J3.1 (CANH), R19.1, U4.7 (CANH)
CAN1_L: J3.2 (CANL), R20.2, U4.6 (CANL)
CAN1_RXD: J1.22 (CAN_1_RX), U4.4 (RXD)
CAN1_SPLIT: C13.1, R19.2, R20.1
CAN1_STB: R21.1, U4.8 (STB)
CAN1_TXD: J1.20 (CAN_1_TX), U4.1 (TXD)
CAP_CP: C3.1, U1.23 (CAP)
COMMON: Q1.2 (S), Q2.2 (S), U1.2 (A), U1.15 (OUT)
CS_PLUS: R2.2, U1.20 (CS+)
DGATE: Q1.1 (G), U1.1 (DGATE)
DIAL_5V: C63.1, J11.1 (DIAL_5V), U8.6 (VOUT)
DIAL_ADC: C61.1, D6.3 (CA), J1.2 (ADC_1), R55.2
DIAL_CLICK: C62.1, D7.3 (CA), J1.206 (GPIO_1), R56.2, R57.2
DIAL_CLICK_RAW: J11.4 (CLICK), R56.1
DIAL_DIV: R54.2, R55.1, R58.1
DIAL_SIG_RAW: J11.2 (SIG), R54.1
DSI_CLK_N: J1.35 (DSI_1_CLK_N), J4.30 (CLK_N)
DSI_CLK_P: J1.37 (DSI_1_CLK_P), J4.28 (CLK_P)
DSI_D0_N: J1.47 (DSI_1_D0_N), J4.38 (LAN0_N)
DSI_D0_P: J1.49 (DSI_1_D0_P), J4.36 (LAN0_P)
DSI_D1_N: J1.41 (DSI_1_D1_N), J4.34 (LAN1_N)
DSI_D1_P: J1.43 (DSI_1_D1_P), J4.32 (LAN1_P)
DSI_D2_N: J1.29 (DSI_1_D2_N), J4.26 (LAN2_N)
DSI_D2_P: J1.31 (DSI_1_D2_P), J4.24 (LAN2_P)
DSI_PANEL_EN: J1.17 (GPIO_9_DSI), J4.16 (RESET), R50.1
EN_5V: R13.2, R14.1, U2.7 (EN/SYNC)
FB_1V8: R17.2, R18.1, U3.3 (FB)
FB_5V: C58.2, R10.2, R11.1, U2.4 (FB)
GND: C1.2, C2.2, C4.2, C5.2, C6.2, C8.2, C9.2, C10.2, C11.2, C12.2, C13.2, C39.2, C40.2, C41.2, C42.2, C43.2, C44.2, C45.2, C46.2, C47.2, C50.2, C51.2, C52.2, C53.2, C54.2, C55.2, C56.2, C57.2, C59.2, C60.2, C61.2, C62.2, C63.2, D1.2, D5.1 (A1), D6.1 (A1), D7.1 (A1), J1.10 (GND), J1.11 (GND), J1.18 (GND), J1.27 (GND), J1.28 (GND), J1.33 (GND), J1.39 (GND), J1.40 (GND), J1.45 (GND), J1.50 (GND), J1.51 (GND), J1.65 (GND), J1.68 (GND), J1.71 (GND), J1.77 (GND), J1.83 (GND), J1.86 (GND), J1.89 (GND), J1.97 (GND), J1.98 (GND), J1.103 (GND), J1.109 (GND), J1.110 (GND), J1.115 (GND), J1.121 (GND), J1.122 (GND), J1.127 (GND), J1.134 (GND), J1.145 (GND), J1.146 (GND), J1.158 (GND), J1.167 (GND), J1.170 (GND), J1.173 (GND), J1.179 (GND), J1.182 (GND), J1.194 (GND), J1.195 (GND), J1.204 (GND), J1.209 (GND), J1.223 (GND), J1.224 (GND), J1.229 (GND), J1.230 (GND), J1.236 (GND), J1.242 (GND), J1.243 (GND), J2.2 (GND), J3.3 (GND), J4.1 (GND), J4.6 (GND), J4.9 (GND), J4.12 (GND), J4.15 (GND), J4.17 (GND), J4.19 (GND), J4.23 (GND), J4.27 (GND), J4.31 (GND), J4.35 (GND), J4.39 (GND), J8.8 (GND), J9.4 (GND), J10.2 (GND), J11.3 (GND), J12.3 (GND), J13.5 (GND), L3.2, Q3.2 (S), R3.2, R4.2, R6.2, R8.2, R11.2, R12.2, R14.2, R18.2, R21.2, R39.2, R42.2, R43.2, R50.2, R52.2, R58.2, U1.13 (GND), U2.3 (AGND), U2.9 (PGND1), U2.11 (PGND2), U3.4 (GND), U3.6 (GND2), U3.9 (EP), U4.2 (GND), U6.2 (PGND1), U6.3 (PGND2), U6.9 (PSP), U6.11 (PSN), U6.19 (AGND), U6.25 (EP), U7.4 (GND), U8.2 (GND)
HGATE: Q2.1 (G), U1.14 (HGATE)
IGN_GATE: C53.1, D5.3 (CA), Q3.1 (G), R51.2, R52.1
IGN_SENSE: J2.3 (IGN), R51.1
IGN_WAKE_N: J1.252 (CTRL_WAKE1_MICO#), Q3.3 (D), R53.2
ILIM: R3.1, U1.11 (ILIM)
IMON: R4.1, U1.10 (IMON)
JTAG_TCK: J1.9 (JTAG_1_TCK), J8.3 (TCK)
JTAG_TDI: J1.1 (JTAG_1_TDI), J8.5 (TDI)
JTAG_TDO: J1.5 (JTAG_1_TDO), J8.4 (TDO)
JTAG_TMS: J1.13 (JTAG_1_TMS), J8.2 (TMS)
JTAG_TRST: J1.3 (JTAG_1_TRST#), J8.6 (TRST)
JTAG_VREF: J1.7 (JTAG_1_VREF), J8.1 (VREF), R48.1
OV_DIV: R5.2, R6.1, U1.5 (OV), U1.16 (OVCLAMP)
PANEL_BIAS_EN: J1.21 (GPIO_10_DSI), R43.1, U6.8 (ENP), U6.10 (ENN)
PANEL_BIAS_VIN: C42.1, R37.2, U6.4 (VIN)
PANEL_BL_LEDA: C52.1, D4.1, J4.2 (LEDA), J4.3 (LEDA)
PANEL_BL_LEDK: J4.4 (LEDK), J4.5 (LEDK), R42.1, U7.6 (FB)
PANEL_BL_PWM: J1.19 (PWM_3_DSI), U7.2 (CTRL)
PANEL_BOOST_SW: D2.2, L2.2, U6.1 (INP1), U6.24 (INP2)
PANEL_CN: C45.1, U6.18 (CN)
PANEL_CP: C44.1, U6.21 (CP)
PANEL_FBN: C49.2, R40.2, R41.1, U6.16 (FBN)
PANEL_FBP: C48.2, R38.2, R39.1, U6.22 (FBP)
PANEL_INV_SW: D3.1, L3.1, U6.13 (OUTN1), U6.14 (OUTN2)
PANEL_PIN_A: J4.7 (VPIN_A), J4.8 (VPIN_A), JP1.2 (COM)
PANEL_PIN_B: J4.10 (VPIN_B), J4.11 (VPIN_B), JP2.2 (COM)
PANEL_VREF: C43.1, R41.2, U6.17 (VREF)
PANEL_VSN: C47.1, C49.1, D3.2, JP1.3 (B), JP2.3 (B), R40.1, U6.15 (VNEG)
PANEL_VSP: C46.1, C48.1, D2.1, JP1.1 (A), JP2.1 (A), R38.1, U6.23 (VPOS)
PG_5V: R16.1, U2.5 (PGOOD)
PWR_BTN: J1.248 (CTRL_PWR_BTN_MICO#), J9.1 (PWR_BTN), R44.1
PWR_EN_MOCI: J1.254 (CTRL_PWR_EN_MOCI), U3.5 (EN)
PWR_FLT: R15.1, U1.12 (FLT)
RECOVERY: J1.246 (CTRL_RECOVERY_MICO#), J9.2 (RECOVERY), R45.1
RESET_MICO: J1.260 (CTRL_RESET_MICO#), J8.7 (RESET), J9.3 (RESET), R46.1
RESET_MOCI: J1.258 (CTRL_RESET_MOCI#), R47.1
RT_5V: R12.1, U2.6 (RT)
SENSE_OUT: Q2.3 (D), R1.2, U1.19 (CS-)
SLEEP_MOCI: J1.256 (CTRL_SLEEP_MOCI#), U8.3 (ON)
SW_5V: C7.2, L1.1, U2.10 (SW)
SW_SENSE: R5.1, R7.1, U1.3 (SW)
TMR: C4.1, U1.9 (TMR)
UART_RXD: J1.147 (UART_3_RXD), J12.2 (RXD)
UART_TXD: J1.149 (UART_3_TXD), J12.1 (TXD)
USB_DN: J1.163 (USB_1_D_N), J13.2 (D_N)
USB_DP: J1.165 (USB_1_D_P), J13.3 (D_P)
USB_ID: J1.161 (USB_1_ID), J13.4 (ID)
USB_VBUS: J1.159 (USB_1_VBUS), J13.1 (VBUS)
UVLO_DIV: R7.2, R8.1, U1.4 (UVLO)
VBACKUP: C39.1, J1.249 (VCC_BACKUP), R49.2
VBACKUP_CELL: J10.1 (VBAT), R49.1
VBAT_F: C2.1, C3.2, D1.1, F1.2, R1.1, R2.1, U1.6 (EN), U1.7 (MODE), U1.22 (VS)
VBAT_IN: F1.1, J2.1 (VBAT)
VCC_LDO: C6.1, U2.2 (VCC)

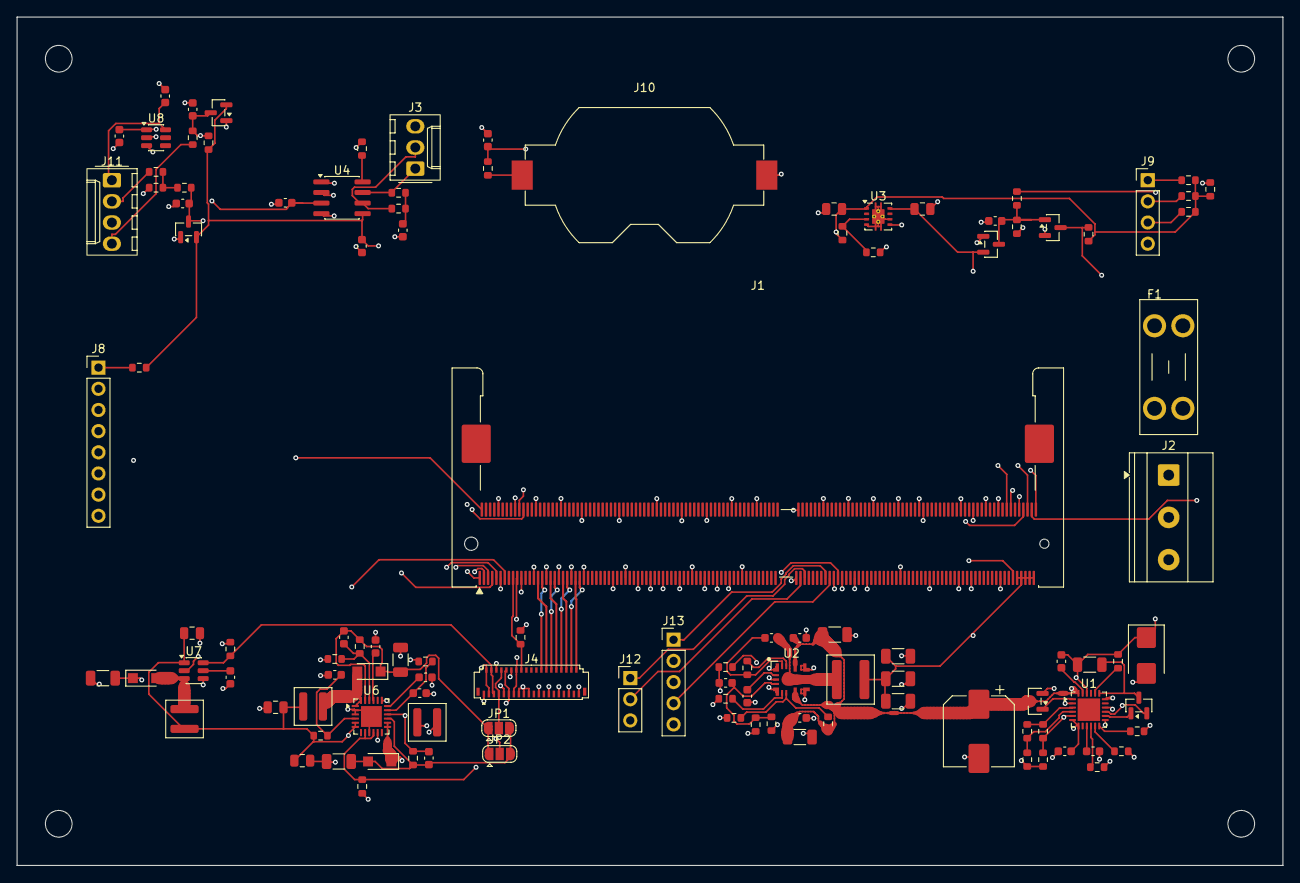
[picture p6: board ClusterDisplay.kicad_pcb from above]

Board: 4 copper layers, 151.9 x 101.8 mm, 119 parts (0 on the bottom side), 90 nets.

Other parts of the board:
MH1, MH2, MH3, MH4: MountingHole_3.2mm_M3

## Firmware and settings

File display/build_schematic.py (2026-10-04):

#!/usr/bin/env python3
"""
build_schematic.py - generates ClusterDisplay.kicad_sch / ClusterDisplay.kicad_sym.

The display-carrier half of Cluster's Android Automotive re-architecture
(see cluster-pcb/README.md and the approved plan at
C:\\Users\\root\\.claude\\plans\\replicated-floating-tiger.md). Ported from
fascia-pcb/build_schematic.py - same real Verdin iMX95 SoM, same real
power tree (LM74930-Q1 + LM61460-Q1 + TLV767-Q1), same real CAN
transceiver (TCAN1044V-Q1) - with fascia's touchscreen-specific
subsystems (PCAP touch, USB-C, the PCM3168A-Q1 audio codec + level
shifters) removed, AND fascia's own SN65DSI85-Q1 DSI-to-LVDS bridge
removed too: this board drives ONE round MIPI-DSI panel behind the
dash's center opening (real target since 2026-09-30: Team Source
Display TST040HDBC-42, 4.0", 720x720, native MIPI-DSI, ICNL9707 driver,
800 nits, -30..+80 C, 101.5 mm active circle that fits the opening
uncropped - it replaced the 350-nit, 127 mm DisplayModule DM-TFTR50-413,
see build_panel()), and that panel speaks DSI natively, so
converting to LVDS and back would be pure overhead fascia's own board
needed (its target panel was LVDS-only) and this one doesn't. Same
script-driven discipline as every sibling project: this script is the
source of truth, never hand-edit the generated .kicad_sch/.kicad_sym.

RE-SCOPED 2026-09-25 (second time this board changed shape): first from
fascia's 10.1" rectangle to a wide bar panel (based on a real i.MX 95
display-pipe-count finding), then from the bar panel to a single round
panel once the user clarified the real intent - restomod, round
displays in the original round openings, with Android specifically on
the CENTER display (the i.MX 95 still only has 1 DSI + 1 LVDS pipe, so
it was never going to drive all 5 - see gauges/build_schematic.py for
where the other 4 round displays live now, wired locally, no OS).

Current stage: the Verdin iMX95 X1 module connector, the 12 V automotive
front end, the 5 V buck, the 1.8 V LDO, the CAN link (to ecu-pcb and to
gauges/'s own S32K144, which needs Android's aggregated gauge data
pushed to it - the user's own request, "the other displays need to get
data from android ... lets add some way for them to communicate"), a
direct MIPI-DSI panel connector (no bridge chip - see build_panel()'s
own docstring for why), the panel's +/-6.5 V bias rails (TPS65131-Q1)
and 15 V/180 mA backlight (TPS61165-Q1), and control/JTAG/RTC. Open:
the panel datasheet's pin table and drawing disagree on which FPC pins
carry +6.5 V vs -6.5 V (hedged with open solder jumpers JP1/JP2), and
its FPC connector (Hirose FH26, 0.3 mm) is inferred, not named.

What IS final at this stage:
  - all 260 X1 pins exist, banked into 5 units by verdin_x1.py (this
    board's own banking - CAN only in the comms bank, no touch/audio)
  - every GND pin is tied to ground, every VCC pin to the +5V rail
  - every pin this board does not use carries a real NoConnect item
  - LM74930-Q1, LM61460-Q1, TLV767-Q1 and TCAN1044V-Q1 are all fully
    wired, every pin netted or NoConnected
  - the module's CAN and full DSI link reach their destinations
"""
import json
import os
import subprocess
import sys
import uuid as uuid_lib

from kiutils.schematic import Schematic
from kiutils.symbol import Symbol, SymbolPin, SymbolLib
from kiutils.items.common import (Position, Property, Effects, Font, Stroke,
                                  Justify)
from kiutils.items.syitems import SyRect, SyPolyLine
from kiutils.items.schitems import (SchematicSymbol, Connection, LocalLabel,
                                    NoConnect, SymbolProjectPath,
                                    SymbolProjectInstance)

HERE = os.path.dirname(os.path.abspath(__file__))
sys.path.insert(0, HERE)

from verdin_pinout import X1_PINS                      # noqa: E402
import verdin_x1                                       # noqa: E402
import parts                                           # noqa: E402

LIB = "ClusterDisplay"
OUT_SCH = os.path.join(HERE, "ClusterDisplay.kicad_sch")
OUT_SYM = os.path.join(HERE, "ClusterDisplay.kicad_sym")
OUT_TABLE = os.path.join(HERE, "sym-lib-table")
OUT_PRO = os.path.join(HERE, "ClusterDisplay.kicad_pro")

# A0. The 260-pin connector alone fills an A2; adding the power tree,
# bridge, CAN and audio blocks filled A1 to the point where two sections
# collided and silently merged a net. Each block now gets its own band
# with real separation between them. This project's KiCad notes record that content
# running off a fixed sheet is invisible in the editor and only shows on
# a real fixed-size export, so main() checks every placement against the
# sheet bounds.
PAPER = "A0"
SHEET_W, SHEET_H = 1189.0, 841.0

GRID = 1.27
PITCH = 2.54          # pin-to-pin spacing down a symbol side
LEAD = 5.08           # pin lead length
UNIT_W = 63.5         # body width; wide enough for names like CTRL_RECOVERY_MICO#
STUB = 5.08           # wire length from a power pin out to its power symbol

# Verdin iMX95 pins that are genuinely supplies, not signals. Everything
# else on the connector is typed passive: this is a board-to-board
# connector, so ERC has no business inferring signal direction from it.
POWER_IN = {"GND", "VCC"}

# X1 signal pins that have somewhere to go. Anything not listed and not
# in X1_NC falls through to bank E's catch-all (real NoConnect) via
# verdin_x1.py's own banking - see that file's header for why this board's
# bank D (CAN only) is deliberately narrower than fascia-pcb's own.
X1_NETS = {
    "CAN_1_TX": "CAN1_TXD",     # module drives the transceiver's TXD
    "CAN_1_RX": "CAN1_RXD",     # transceiver's RXD drives the module
    # MIPI DSI into the SN65DSI85-Q1. These are the pairs that stay ON
    # the carrier - the long run to the panel is LVDS out of the bridge.
    "DSI_1_D0_P": "DSI_D0_P", "DSI_1_D0_N": "DSI_D0_N",
    "DSI_1_D1_P": "DSI_D1_P", "DSI_1_D1_N": "DSI_D1_N",
    "DSI_1_D2_P": "DSI_D2_P", "DSI_1_D2_N": "DSI_D2_N",
    # DSI_1_D3 is unused: the TST040HDBC-42 has three data lanes.
    "DSI_1_CLK_P": "DSI_CLK_P", "DSI_1_CLK_N": "DSI_CLK_N",
    # I2C_2_DSI_SDA/SCL dropped: that was the SN65DSI85-Q1 bridge's own
    # config bus, and there is no bridge on this board anymore (direct
    # DSI to the panel - see build_panel()'s own docstring). They fall
    # through to bank C's genuinely-unused pins.
    "GPIO_9_DSI": "DSI_PANEL_EN",
    # Rotary dial (2026-10-02): a 360-degree potentiometer with a push
    # switch, the way automakers add a controller to a screen with no touch.
    # The wiper reads on Verdin ADC_1 (X1 pin 2, ADC_IN0; the datasheet's
    # absolute maximum for ADC pins is 2.1 V, so the pot is powered from the
    # 1.8 V rail), the click on GPIO_1 (X1 pin 206, 1.8 V logic).
    "ADC_1": "DIAL_ADC",
    "GPIO_1": "DIAL_CLICK",
    # CTRL_SLEEP_MOCI# (X1 pin 256) is the module's "enable for carrier
    # peripherals that must be turned off during sleep" (datasheet), 1.8 V.
    # It switches the dial sensor's 5 V supply.
    "CTRL_SLEEP_MOCI#": "SLEEP_MOCI",
    # Ignition wake (rev B): Verdin datasheet Table 9/30 - pin 252 is the
    # default, only guaranteed-compatible wake-up pin, 1.8 V, "wake-capable
    # pin that allows the system to resume from sleep mode", also a regular
    # GPIO (GPIO1_IO10). Active-low by name (the # suffix); software picks
    # the edge. Driven by the ignition network in build_control().
    "CTRL_WAKE1_MICO#": "IGN_WAKE_N",
    "GPIO_10_DSI": "PANEL_BIAS_EN",   # TPS65131-Q1 ENP/ENN
    "PWM_3_DSI": "PANEL_BL_PWM",      # TPS61165-Q1 CTRL (PWM dimming)
    # Control and sequencing.
    "CTRL_PWR_EN_MOCI":  "PWR_EN_MOCI",
    "CTRL_RESET_MOCI#":  "RESET_MOCI",
    "CTRL_RESET_MICO#":  "RESET_MICO",
    "CTRL_PWR_BTN_MICO#": "PWR_BTN",
    "CTRL_RECOVERY_MICO#": "RECOVERY",
    "JTAG_1_TCK":   "JTAG_TCK",
    "JTAG_1_TMS":   "JTAG_TMS",
    "JTAG_1_TDI":   "JTAG_TDI",
    "JTAG_1_TDO":   "JTAG_TDO",
    "JTAG_1_TRST#": "JTAG_TRST",
    "JTAG_1_VREF":  "JTAG_VREF",
    "VCC_BACKUP":   "VBACKUP",
    # Bring-up access (review fix 2026-10-04): the A55 console UART and the
    # USB 2.0 OTG port, on bench-only headers (J12, J13). UART_3 is the Verdin
    # standard "main OS terminal" (datasheet), 1.8 V logic. USB_1_VBUS is a
    # 5 V input (abs max 5.5 V) that only detects VBUS.
    "UART_3_RXD": "UART_RXD", "UART_3_TXD": "UART_TXD",
    "USB_1_D_P": "USB_DP", "USB_1_D_N": "USB_DN",
    "USB_1_VBUS": "USB_VBUS", "USB_1_ID": "USB_ID",
}

# X1 pins this board deliberately does not use, outside the unused bank.
# Each one the Verdin datasheet explicitly permits leaving floating, or
# that this design has no use for. They get real NoConnect items, same as
# bank E, rather than being left to show up as ERC noise.
X1_NC = {
    "DSI_1_D3_P", "DSI_1_D3_N",  # panel has 3 lanes, not 4
    "I2C_2_DSI_SDA", "I2C_2_DSI_SCL",  # bridge-config bus; no bridge on this board
    "CTRL_FORCE_OFF_MOCI#",  # datasheet: "can be left floating"
    "TAMPER0", "TAMPER1",    # SoC tamper detect, unused here
    "PWR_1V8_MOCI",          # the carrier makes its own 1.8 V
    "PMIC_PGOOD",            # module-side power good, not used by us
}


def U():
    return str(uuid_lib.uuid4())


def snap(v):
    """Round onto KiCad's 1.27 mm schematic grid.

    Applied at every placement entry point. This project's KiCad notes
    record that off-grid pin/wire endpoints produce one real
    `endpoint_off_grid` ERC violation each, even when every connection is
    otherwise correct.
    """
    return round(round(v / GRID) * GRID, 2)


# ---------------------------------------------------------------------------
# Symbol library
# ---------------------------------------------------------------------------
lib_symbols = {}          # lib_id -> Symbol
unit_pin_offsets = {}     # (unit_index, pin_number) -> (dx, dy) in symbol space
unit_heights = {}         # unit_index -> drawn body height (mm)


def build_x1_symbol():
    """
    The Verdin iMX95 X1 connector as one multi-unit KiCad symbol.

    Each unit gets its pins split down its two sides, first half on the
    left, second half on the right, in ascending pin order so the drawing
    can be read against the datasheet's own tables.

    Real SKU chosen (2026-09-28): "Verdin iMX95 Hexa 8GB WB IT" - a real,
    confirmed-orderable Toradex product (independently listed on both
    Mouser US and Mouser UK under this exact name), not a placeholder.
    Hexa (6-core) + 8GB LPDDR5 gives real headroom for Android Automotive
    (a real OS + display compositor workload, not a bare-metal firmware
    role like this family's other MCU-based boards), and IT (industrial
    temperature) matches every other automotive-grade part on this board
    rather than a commercial-temp module in a dash-mounted enclosure.
    Toradex's own internal ordering code for this SKU wasn't independently
    confirmed - verify the exact Toradex part number at purchase time,
    same real "confirmed product, purchasing pass still owed" status
    ecu-pcb's own BOM already carries for its own long-lead parts.
    """
    lib_id = f"{LIB}:Verdin_iMX95_X1"
    parent = Symbol.create_new(
        id=lib_id, reference="J", value="Verdin iMX95 Hexa 8GB WB IT",
        footprint=parts.FOOTPRINTS["Verdin_iMX95_X1"],
        datasheet="https://docs.toradex.com/200007-verdin_imx95_datasheet.pdf")
    parent.pinNames = True
    parent.pinNamesOffset = 0.508
    parent.hidePinNumbers = False

    for idx, (label, desc, entries) in enumerate(verdin_x1.units(), start=1):
        half = -(-len(entries) // 2)          # ceil, so left side takes the extra
        left, right = entries[:half], entries[half:]
        rows = max(len(left), len(right), 1)
        height = rows * PITCH + PITCH
        unit_heights[idx] = height

        child = Symbol(libraryNickname=None, entryName="Verdin_iMX95_X1",
                       unitId=idx, styleId=1)
        child.graphicItems.append(SyRect(
            start=Position(-UNIT_W / 2, -height / 2),
            end=Position(UNIT_W / 2, height / 2),
            stroke=Stroke(width=0.254, type="default")))
        child.graphicItems[-1].fill.type = "background"

        def add_side(items, x_tip, angle):
            n = len(items)
            for i, (pin, name) in enumerate(items):
                # Symbol space is Y-up, so the first entry needs the
                # largest y to land at the TOP of the drawn body.
                py = ((n - 1) * PITCH) / 2 - i * PITCH
                etype = "power_in" if name in POWER_IN else "passive"
                child.pins.append(SymbolPin(
                    electricalType=etype, graphicalStyle="line",
                    position=Position(round(x_tip, 2), round(py, 2), angle),
                    length=LEAD, name=name, number=str(pin)))
                unit_pin_offsets[(idx, pin)] = (round(x_tip, 2), round(py, 2))

        # Pin angle points from the connection tip toward the body, so a
        # left-hand pin is 0 and a right-hand pin is 180.
        add_side(left, -(UNIT_W / 2 + LEAD), 0)
        add_side(right, UNIT_W / 2 + LEAD, 180)
        parent.units.append(child)

    lib_symbols[lib_id] = parent
    return lib_id


def build_power_symbol(net, is_gnd):
    lib_id = f"{LIB}:PWR_{net}"
    sym = Symbol.create_new(id=lib_id, reference="#PWR", value=net)
    sym.isPower = True
    sym.pinNames = True
    sym.pinNamesOffset = 0
    sym.pinNamesHide = True
    sym.hidePinNumbers = True
    sym.properties[0].effects.hide = True
    stroke = Stroke(width=0.254, type="default")
    if is_gnd:
        sym.properties[1].position = Position(0, -4.6, 0)
        shapes = ([(0, 0), (0, -1.27)],
                  [(-1.27, -1.27), (1.27, -1.27)],
                  [(-0.762, -1.905), (0.762, -1.905)],
                  [(-0.254, -2.54), (0.254, -2.54)])
    else:
        sym.properties[1].position = Position(0, 3.9, 0)
        shapes = ([(0, 0), (0, 2.54)], [(-1.016, 2.54), (1.016, 2.54)])
    for pts in shapes:
        sym.graphicItems.append(SyPolyLine(
            points=[Position(a, b) for a, b in pts], stroke=stroke))
    sym.pins = [SymbolPin(electricalType="power_in", graphicalStyle="line",
                          position=Position(0, 0, 90), length=0,
                          name=net, number="1", hide=True)]
    lib_symbols[lib_id] = sym
    return lib_id


def build_pwr_flag(net):
    """
    PWR_FLAG equivalent - asserts that `net` is driven from off-sheet.

    +5V enters this stage with no regulator on the sheet yet, so ERC's
    power_pin_not_driven fires without this. Drawn as an arrow so it does
    not read as another supply if opened in the GUI.
    """
    lib_id = f"{LIB}:PWR_FLAG_{net}"
    sym = Symbol.create_new(id=lib_id, reference="#FLG", value=f"PWR_FLAG {net}")
    sym.isPower = True
    sym.pinNames = True
    sym.pinNamesOffset = 0
    sym.pinNamesHide = True
    sym.hidePinNumbers = True
    sym.properties[0].effects.hide = True
    sym.properties[1].position = Position(0, 3.9, 0)
    stroke = Stroke(width=0.254, type="default")
    for pts in ([(0, 0), (0, 2.54)], [(0, 2.54), (-0.889, 1.651)],
                [(0, 2.54), (0.889, 1.651)]):
        sym.graphicItems.append(SyPolyLine(
            points=[Position(a, b) for a, b in pts], stroke=stroke))
    sym.pins = [SymbolPin(electricalType="power_out", graphicalStyle="line",
                          position=Position(0, 0, 90), length=0,
                          name=net, number="1", hide=True)]
    lib_symbols[lib_id] = sym
    return lib_id


# ---------------------------------------------------------------------------
# Schematic
# ---------------------------------------------------------------------------
sch = Schematic.create_new()
sch.paper.paperSize = PAPER
sch.uuid = U()


def place(lib_id, ref, value, x, y, unit=1, hide_ref=False, body_h=None):
    """
    Place a symbol instance.

    `body_h` is the drawn height of THIS unit. A multi-unit symbol carries
    one set of property positions shared by every unit, so leaving them at
    the library default stacks the reference and value on top of each
    other in the middle of the body. Passing the unit's own height moves
    the reference above it and the value below it. Note the sheet is
    Y-down, so "above" is the smaller y.
    """
    x, y = snap(x), snap(y)
    inst = SchematicSymbol(
        libraryNickname=lib_id.split(":")[0], entryName=lib_id.split(":")[1],
        position=Position(x, y, 0), unit=unit, inBom=True, onBoard=True,
        uuid=U())
    src = lib_symbols[lib_id]
    for i, p in enumerate(src.properties):
        if body_h is not None and i in (0, 1):
            gap = body_h / 2 + 2.54
            pos = Position(x, y - gap if i == 0 else y + gap, 0)
        else:
            pos = Position(x + p.position.X, y - p.position.Y, 0)
        prop = Property(key=p.key, value=(ref if i == 0 else
                                          (value if i == 1 else p.value)),
                        id=i, position=pos,
                        effects=Effects(font=Font(width=1.27, height=1.27)))
        if i == 0 and hide_ref:
            prop.effects.hide = True
        if i >= 2:
            prop.effects.hide = True
        inst.properties.append(prop)
    inst.instances.append(SymbolProjectInstance(
        name=LIB, paths=[SymbolProjectPath(sheetInstancePath=f"/{sch.uuid}",
                                           reference=ref, unit=unit)]))
    sch.schematicSymbols.append(inst)
    return inst


def add_wire(x1, y1, x2, y2):
    sch.graphicalItems.append(Connection(
        type="wire",
        points=[Position(snap(x1), snap(y1)), Position(snap(x2), snap(y2))],
        stroke=Stroke(width=0.0, type="default"), uuid=U()))


def pin_xy(unit, pin, sym_x, sym_y):
    """Sheet coordinates of an X1 pin.

    Symbol space is Y-up while the sheet is Y-down, so the symbol-space
    offset is added in X and SUBTRACTED in Y.
    """
    dx, dy = unit_pin_offsets[(unit, pin)]
    return snap(sym_x + dx), snap(sym_y - dy)


# ---------------------------------------------------------------------------
# Generic parts and the declarative net list
# ---------------------------------------------------------------------------
# Rails get power symbols; everything else gets a stub wire and a local
# label. This project's KiCad notes are explicit that the two mechanisms
# do NOT merge - a label "GND" makes net "/GND" while a power symbol makes
# global "GND" - so each net must pick one and stick to it.
# VBAT_F and +12V_PROT are rails too, not signals: they feed power_in
# pins, so ERC needs them driven. Both arrive through passive parts (a
# fuse, and the ideal-diode FET), so nothing on the sheet "drives" them
# and each needs a PWR_FLAG the same way GND and +5V do.
# PANEL_BIAS_VIN is TPS65131-Q1's RC-filtered control supply (+5V through
# R37): ERC cannot trace a power pin through a resistor, so it gets the
# same PWR_FLAG treatment as the other rails.
POWER_NETS = {"GND", "+5V", "+12V_PROT", "+1V8", "+3V3", "VBAT_F",
              "PANEL_BIAS_VIN"}

# net -> a real (x, y) on that net, for anchoring PWR_FLAGs. This project's
# KiCad notes record that a flag merged only by name, with nothing
# touching it graphically, does not satisfy power_pin_not_driven.
power_net_points = {}

# Rails that a real part actually drives, i.e. something on the net has a
# power_out pin. Those must NOT get a PWR_FLAG: two power outputs on one
# net is a pin_to_pin conflict, and the flag exists precisely to stand in
# for a driver that is not on the sheet.
driven_nets = set()

# Every coordinate a net is terminated at, so two blocks drifting into
# each other can be caught by construction. Keyed on the point, valued
# with (net, owning reference). Covers pin positions AND stub endpoints -
# an earlier version only scanned label positions and therefore missed a
# stub whose endpoint landed on another block's pin.
net_points = {}

generic_pins = {}      # lib_id -> [(num, name, etype), ...]
generic_offsets = {}   # (lib_id, num) -> (dx, dy) symbol space
generic_heights = {}   # lib_id -> body height
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

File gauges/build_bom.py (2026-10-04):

#!/usr/bin/env python3
"""
build_bom.py - generates the gauges/ board's bill of materials straight
from the real schematic, plus a standalone HTML page.

*** ADAPTED FROM ecu-pcb/build_bom.py (2026-09-27) *** same real
generated-not-hand-maintained discipline, same coverage/value-spelling
self-checks, same HTML template - only the per-board MPN table and
header copy are new.

WHY GENERATED, NOT HAND-MAINTAINED: every other artefact in this family
is regenerated from source rather than hand-edited (see
build_schematic.py / build_pcb.py). Reference designators, values,
packages and quantities here all come from ClusterGauges.kicad_sch
itself, so the BOM cannot disagree with the board.

WHAT IS AND IS NOT VERIFIED - stated plainly, same discipline as
ecu-pcb's own BOM:
  * ACTIVE parts and connectors carry REAL manufacturer part numbers
    where build_schematic.py's own comments state one - that provenance
    is in that file, not invented here.
  * A few parts are genuinely NOT pinned to an exact orderable part
    number in the schematic - the MCU (S32K144's exact memory/package
    suffix), the front-end TVS and MOSFETs' exact manufacturer, and the
    fuse's exact Littelfuse 297-series suffix. These get their own
    "needs real part selection" section below rather than a fabricated
    precise-looking part number - see build_schematic.py's own header
    for what IS cited (S32K144 pin-mux research, PMV37ENEA/SMCJ33A
    parametric choices) versus what's a real remaining purchasing task.
  * PASSIVES are specified parametrically - value, package, and the
    AEC-Q200 requirement - same real reasoning as ecu-pcb's own BOM:
    a 0402/0603 resistor is a commodity chosen on value/package/
    tolerance/qualification, not a unique design-critical device.
  * LIVE PRICING AND STOCK ARE NOT INCLUDED.

Run:  python build_bom.py          -> console summary + ClusterGauges_BOM.html
"""
import io
import os
import re
from collections import defaultdict

from kiutils.schematic import Schematic
from kiutils.utils import sexpr

import sys
sys.path.insert(0, os.path.join(os.path.dirname(os.path.abspath(__file__)), "..", "tools"))
import passive_catalog  # noqa: E402  real orderable passives, see that file

HERE = os.path.dirname(os.path.abspath(__file__))
SCH = os.path.join(HERE, "ClusterGauges.kicad_sch")
OUT_HTML = os.path.join(HERE, "ClusterGauges_BOM.html")
PCB = os.path.join(HERE, "ClusterGauges.kicad_pcb")

# Real manufacturer part numbers for every non-passive that has one
# stated in build_schematic.py's own comments. Keyed by the distinctive
# token that appears in the schematic's own Value string, so this table
# cannot drift away from the schematic without the lookup simply
# failing loudly rather than reporting a stale part.
#   token -> (MPN, manufacturer, description, qualification)
MPN = {
    "S32K144":    ("FS32K144HAT0MLHT", "NXP",
                   "S32K144 Arm Cortex-M4F, 80 MHz (112 MHz HSRUN), 512 KB flash, CAN FD, "
                   "LQFP-64 (suffix MLH = 64-LQFP; MLL would be the 100-pin part), -40..125 C, "
                   "tape and reel; pin-mux verified against NXP's S32K1xx Reference Manual. Orderable "
                   "part number as listed by Newark, Mouser and TrustedParts (checked 2026-10-04); "
                   "confirm the suffix on the NXP part page when ordering",
                   "AEC-Q100 Grade 1"),
    "LMR33630-Q1": ("LMR33630BRNXRQ1", "TI", "3A synchronous buck regulator, +5V rail", "AEC-Q100 G1"),
    "LM74930-Q1":  ("LM74930QRGERQ1", "TI", "Automotive ideal-diode surge stopper with OV clamp and circuit breaker, VQFN-24 RGE; TI lists it Active/Production (same part as display/)", "AEC-Q100 Grade 1"),
    "PMV55ENEA":   ("PMV55ENEAR", "Nexperia", "60V N-ch MOSFET, VGS +-20V, SOT-23: LM74930 pass and ideal-diode FET pair (orderable suffix R = reel)", "AEC-Q101"),
    "TLV733P-Q1":  ("TLV73333PQDBVRQ1","TI", "300mA LDO, +3.3V rail", "AEC-Q100 G1"),
    "TJA1043T":    ("TJA1043T/1J", "NXP", "High-speed CAN transceiver with wake, real wiring reused verbatim from ecu-pcb", "AEC-Q100"),
    # U6-U9 are the board-side FPC CONNECTORS the GC9A01 modules plug into
    # (the module itself is a companion part, appended below). Part number
    # follows Amphenol's F32Q-1A7H1-110NN scheme (NN = contacts): the 11008,
    # 11012, 11020, 11022 and 11050 variants were verified on DigiKey, 11018
    # is the 18-contact member (PATTERN: confirm in the cart). 0.5 mm pitch,
    # right-angle ZIF, BOTTOM contact - order the module's FPC accordingly.
    "RFA401280B-AYW-DNF1": ("F32Q-1A7H1-11018", "Amphenol FCI",
                             "18-position 0.5mm FPC connector, right-angle ZIF, bottom contact, one per GC9A01 "
                             "module [PATTERN: confirm this exact part number in the distributor cart]", "-"),

    "PMV37ENEA":  ("PMV37ENEA", "Nexperia", "N-MOSFET, 12V-rail reverse-protection gate switch / shared backlight low-side switch", "AEC-Q101"),
    "SMCJ33A":    ("SMCJ33A (multi-source)", "Littelfuse / onsemi / Vishay (industry-standard P/N)",
                    "SMC-package TVS diode, 33V standoff, 12V-rail transient protection - not pinned to one vendor, real industry-standard part number", "AEC-Q101"),

    # F1's REAL placed schematic footprint is the HOLDER, not the fuse
    # element (a blade fuse plugs into it, never its own KiCad
    # footprint) - matches on the holder, same real Keystone 3568 part
    # every sibling board's own fuse holder already uses. The element
    # itself is a separate, non-placed orderable line, appended below
    # (same real split ecu-pcb's own BOM makes).
    "Littelfuse 297": ("3568", "Keystone", "Mini blade fuse holder, PCB mount (fuse element ordered separately)", "-"),

    "XAL5050-103ME": ("XAL5050-103MEC", "Coilcraft", "10uH shielded molded power inductor, Isat 4.9A, DCR 41mR typ, 5x5x5mm, AEC-Q200 - meets the LMR33630-Q1 datasheet's rule that Isat not be below the 4.1A low-side limit (datasheet Document 806-1 family; trailing C = 7in reel ordering code)", "AEC-Q200"),
    "Tag-Connect": ("TC2030-IDC-NL", "Tag-Connect", "SWD programming/debug connector, 2x3 1.27mm, no-legs cable version", "-"),

    # Rev B (2026-09-30), gateway architecture: private CAN1 link to
    # display/ and Hall speed input conditioning.
    "TCAN1044V-Q1": ("TCAN1044VDRQ1", "TI", "Automotive CAN FD transceiver w/ VIO pin, SOIC-8 - private CAN1 link to display/ (same part as display/'s transceiver; datasheet SLLSF17D)", "AEC-Q100 Grade 1"),
    "BAV99-Q":      ("BAV99-Q (confirm reel suffix at order time)", "Nexperia", "Dual series high-speed switching diode, SOT-23, used as a rail-to-rail input clamp on the speed and ignition inputs (pin 3 signal, pin 1 GND, pin 2 +3V3; datasheet Rev. 8)", "AEC-Q101"),
}
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

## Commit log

2026-09-23 Scaffold Cluster: architecture README, power stage + MCU core schematic
    Digital instrument cluster for a 1966 Mustang, sibling to Manifold/ECU/
    Thermo/Fascia. README documents the researched architecture (S32K144
    hub, 4x GC9A01 aux gauges, BT817AQ-driven ST7701S speedo, CAN + local
    resistive senders). build_schematic.py generates the power stage
    (reused verbatim from Manifold/Thermo) and the MCU's fixed pins
    (crystal/SWD/RESET/power) - round-trips clean, ERC-clean except the
    same 4 expected tool-limitation findings every sibling board has at
    this stage.
    [Cluster.kicad_sch]
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2026-09-23 Steps 2-3: CAN0 transceiver + 4x GC9A01 aux gauges wired
    Step 2: reused ecu-pcb's real, already-verified TJA1043T CAN transceiver
    pin table and wiring topology verbatim (single CAN0 instance).
    Step 3: registered the real 18-pin FPC table from Raystar's own
    RFA401280B-AYW-DNF1 datasheet for the 4x GC9A01 aux gauges. Real finding
    from reading the datasheet rather than assuming a generic GC9A01
    breakout: backlight is a bare LED anode/cathode pair, not a logic-level
    enable pin - wired with per-display series resistors from +5V and a
    shared low-side MOSFET switch (reusing the power stage's own PMV37ENEA),
    not 4 GPIO-driven logic pins.
    Two real bugs caught and fixed by the script's own checks, n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
    [Cluster.kicad_sch]
2026-09-23 Step 4: BT817AQ speedo co-processor + ST7701S module wired
    Registered BT817AQ's real 64-pin VQFN table from Bridgetek's own
    datasheet and the BH021WVC02 module's real 40-pin FPC table from
    Panox's own datasheet. Real finding along the way: BT817A's VCC1V2
    core rail is a genuine external 1.28V supply (not internally regulated
    from VCC), so a new TPS7A16-Q1 adjustable LDO + FB divider was added,
    sized from TI's own VREF spec. RGB666 wiring uses the module's own
    documented bit order (DB0=Blue LSB..DB17=Red MSB) to map BT817AQ's
    R7-R2/G7-G2/B7-B2 correctly. Speedo backlight reuses the same real
    "series resistor + shared MOSFET switch" LED treatment as the aux
    gauges, this time PWM-driven from BT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
    [Cluster.kicad_sch]
2026-09-23 Step 5: sensor ADC front end wired; schematic now fully wired
    Fuel/oil/temp resistive dividers sized per-sender from the real
    published curves (fuel/oil share a 47R pull-up given their similar
    10-70ish-ohm range; coolant temp gets its own 100R pull-up for its much
    wider 10-300R range). Battery voltage divider (49.9k/10k) scaled for
    the real 9-16V automotive range with margin below the ADC's 3.3V rail.
    ERC is down to exactly the 4 baseline findings every sibling board's
    finished schematic carries (VDDA/U2-VIN/+5V power_pin_not_driven,
    SWCLK driven off-sheet) - every real forward stub from Steps 1-5 is now
    resolved except the genuine off-board harness connections pending Step
    6. Also grew the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
    [Cluster.kicad_sch]
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2026-09-23 PCB layout: first-pass placement, DRC-clean
    build_pcb.py adapts thermo-pcb's proven framework with one real, new
    piece: a fixed target outline (441x105.5mm, the real inner dash-opening
    dimension) instead of a free width sweep, with the 5 display connectors
    pulled out and placed in a row at evenly-spaced X positions (real
    hole-center spacing isn't individually dimensioned in the user's
    reference image - confirmed proceeding with estimates).
    Three real bugs caught by the DRC loop and fixed, not eyeballed: packed
    parts landing with zero margin against the board's top edge, a page
    size smaller than the board itself (drove the centering offset
    negative), and a genuine coordinate-math bug in the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
    [Cluster.kicad_pcb]
2026-09-23 Spread PCB placement into real functional zones + back-silk logo
    User feedback: the first-pass layout bunched everything into one
    corner, leaving most of the board empty. Reworked into real zones -
    each display gets its own local cluster of immediate support parts
    directly above it (the speedo's whole BT817AQ+LDO+crystal subsystem
    included, a real short-trace reason not just visual balance), and the
    board-wide subsystems (power, MCU, CAN0, backlight switch, sender
    dividers) pack independently then arrange left-to-right with equal
    spacing across the board's real full width - same "bucket into
    functional blocks" precedent ecu-pcb's own PCB already established.
    Also added the real back-silkscr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
    [Cluster.kicad_pcb]
2026-09-23 Replace back-silkscreen logo with an original tach-face design
    User asked for something cooler than the reused sibling-board logo.
    Drew a real tachometer face (0-8 sweep, redline arc, resting needle,
    "x1000 RPM" caption) plus a CLUSTER wordmark directly as KiCad graphic
    primitives (GrCircle/GrArc/GrLine/GrText) - original artwork, not
    traced from any existing source, genuinely on-theme for an instrument
    cluster board.
    Real detail that needed getting right: back-layer shapes aren't
    auto-mirrored by KiCad the way text glyphs are (which use an effects
    flag instead) - every primitive routes through one shared mirror
    helper so the constructive layout code stays in natural left-to-right
    reading o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
    [Cluster.kicad_pcb]
2026-09-23 Remove unused logo assets superseded by the generated tach-face art
    both.kicad_sym/both.png were only needed by the file-based logo loader
    this project's own build_pcb.py no longer has, now that the back
    silkscreen is generated directly as KiCad primitives instead.
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2026-09-23 Right-size board height to real content, not the opening's own max
    User feedback: "i think we can make it smaller. no reason to make it so
    big right?" - correct. The board's width genuinely can't shrink below
    ~441mm (the 5 connectors have to reach across the real dash-opening
    width to land under their own gauge holes), but the height had no such
    constraint - it was anchored to the opening's own 105.5mm inner
    dimension as if the board needed to fill it vertically, which was
    never actually required.
    Reworked the layout order: pack local clusters and core zones first to
    find their real sizes, then derive board_height from what's actually
    stacked (margins + display row + local clusters + core z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
    [Cluster.kicad_pcb]
2026-09-23 Add 6 real M3 standoff holes; fix two bugs this surfaced
    4 corners + 2 along the top edge - a board this long and thin needs
    more than 2 support points to avoid real flex/vibration in a
    dash-mounted automotive environment.
    Two real bugs caught and fixed by the same build/verify/fix loop:
    1. A first attempt placed the 2 extra holes at naive 1/3 and 2/3
    board-width fractions and landed on R4/R5 and U1 - fixed by using
    the actual empty gaps between core zones (captured while they're
    being placed) instead of a guessed fraction.
    2. Adding the holes shrank the tach-face artwork's own safe drawing
    area (GAUGE_R 21.5mm -> 15.6mm), but its internal tick/number/
    caption geometry was al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
    [Cluster.kicad_pcb]
2026-09-23 Route the PCB: 251/252 nets via FreeRouting, VIN_PROT trunk widened, GND/+3V3 zones poured
    route_board.py adapts thermo-pcb's own DSN/SES FreeRouting pipeline
    (export via pcbnew.ExportSpecctraDSN, headless FreeRouting, import via
    pcbnew.ImportSpecctraSES, then two additive post-route passes: widen
    the VIN_PROT power trunk from its 0.2mm routing width back up to
    0.6mm, then pour+fill GND/+3V3 zones on the inner layers, one zone per
    subprocess to dodge a known pcbnew multi-zone-fill segfault).
    FreeRouting converged 251/252 nets on the first pass; one net
    (AUX_DC3, U9 pin 13 -> U1 pin 24) stayed stuck across 6 retries - real
    autorouter congestion around this board's 0.5mm-pitch parts, needs a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
    [Cluster.kicad_pcb]
2026-09-24 Fully route the PCB: 252/252 nets, 0 unrouted
    The prior commit landed 251/252 (one net, AUX_DC3, stuck across 6
    FreeRouting retries). FreeRouting is stochastic and its outcome tracks
    the exact DSN content, so regenerating the board fresh (no code
    change) and re-routing gave the export a different implicit seed -
    this cycle converged fully, 0 unrouted, in 7 auto-router passes.
    DRC-clean, same documented categories as before, no hand-routing
    needed.
    [Cluster.kicad_pcb]
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2026-09-25 display/: switch to a real bigger round panel, drop the LVDS bridge
    Per the user's request to find a slightly larger round display for the
    center to maximize the custom faceplate: DisplayModule DM-TFTR50-413
    (5.0", 1080x1080, native MIPI-DSI, HX8399 driver, 350 nits, -20 to
    60C, $119, real datasheet available) - meaningfully bigger than the
    stock 91.44mm speedo opening, and a real, currently-orderable part.
    Because this panel speaks MIPI-DSI natively, fascia-pcb's own reason
    for the SN65DSI85-Q1 DSI-to-LVDS bridge (its target panel was LVDS-
    only, above the Verdin module's native LVDS ceiling) doesn't apply
    here - there's no LVDS anywhere in this board's real requirement.
    build_panel() repl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
    [ClusterDisplay.kicad_sch]
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2026-09-25 PCB layout for gauges/: 447.1x42.6mm, real placement, DRC-clean
    Adapted from the original cluster-pcb/build_pcb.py rather than written
    fresh - same skyline packer, zone-based placement, mounting holes, and
    tach-face silkscreen art, all still real and unchanged.
    Two real, deliberate differences from the original file:
    - DISPLAY_REFS drops J3 (speedo, now on display/) but keeps U6/U7/U8/
    U9 at their ORIGINAL 5-slot hole-position fractions (slots 0, 1, 3,
    4 - skipping slot 2) rather than re-spreading 4 connectors evenly
    across 4 new slots. The real dash holes for these 4 gauges haven't
    moved just because the speedo's own board moved to display/ -
    naive even-4-way spacing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
    [ClusterGauges.kicad_pcb]
2026-09-26 Fix a real duplicate reference: backlight inductor was L1, same as the power tree's own buck inductor
    Caught while preparing for PCB layout, not by ERC (KiCad's own ERC
    doesn't flag duplicate references the way it flags electrical issues).
    Real consequence if this had reached build_pcb.py: that script reads
    parts back out of the schematic keyed by reference string, so the
    second "L1" instance would have silently overwritten the first in the
    parts dict - one of the two real inductors would have vanished from
    the board with no error, not even a net-count mismatch (since both
    inductors' own net names differ, the assertion checking sch-vs-PCB net
    pin counts per net wouldn't have caught a whole m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
    [ClusterDisplay.kicad_sch]
2026-09-26 PCB layout for display/: 364.8x124.0mm, real placement, DRC-clean
    New layout strategy, not a copy of gauges/ or the original board -
    this board has no real fixed target width (nothing pins its position
    across the dash the way gauges/'s 4 aux-gauge holes do). Its shape is
    instead driven by ONE real mechanical fact: the Toradex Verdin iMX95
    module is 69.6x47mm (real, confirmed spec) and plugs flat into the
    SODIMM-260 socket (J1), reserving real board area nothing else can
    use. That keepout is sized generously (90x90mm), flagged honestly as
    a first-pass reservation rather than a precisely modeled fact - the
    real socket courtyard is an irregular ~27x76.5mm shape (angled
    ejector-latch cutout, pul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
    [ClusterDisplay.kicad_pcb]
2026-09-26 Shrink display/ from 364.8x124.0 to 180.8x163.9mm; add the real tach-face art
    User asked directly: "does the SOMM board need to be so large?" - no,
    it didn't. Two real, separate causes, both fixed:
    1. The board's WIDTH was actually driven by laying all 5 circuit zones
    out in a single left-to-right row (summing to ~359mm) - a layout
    choice copied from gauges/'s own CORE_ZONES arrangement without
    reconsidering that gauges/'s single row exists because of a real
    external constraint (4 aux-gauge connectors reaching real, fixed
    dash holes) that doesn't apply to this board at all. Added
    pack_sized_blocks() - the same real skyline algorithm, generalized
    to pack pre-sized rectan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
    [ClusterDisplay.kicad_pcb]
2026-09-27 display: unify layout pack around module keepout, redesign back art placement
    Replace the top-band/zone-band split with a single 2D pack: the Verdin
    module keepout is a real fixed obstacle (seeded skyline), and J4 plus
    all 5 circuit zones are packed into the space actually left around it.
    Board shrinks from 180.8x163.9mm to a more honest 204.5x114mm with no
    leftover strip beside J4.
    Back-silkscreen tach face + wordmark placement is redone too: a first
    side-by-side layout (copied from gauges/) put the gauge right where
    J1's real SODIMM alignment pegs are, since the previous safe-area math
    conflated front-side zone content with the actual back-side constraint
    (real thru-hole pads only - NPTH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
    [ClusterDisplay.kicad_pcb]
2026-09-27 display: replace bin-packed layout with a deliberate 2-column grid
    The previous unified pack read as algorithmically arranged, not
    designed: the block-packer let J4 (the panel connector) land wherever
    was tightest among the 5 zones, disconnected from any neighbor, and
    each zone started at its own independent X with no shared alignment.
    Zones also mixed part orientations internally whenever a 90-degree
    rotation packed slightly tighter.
    Replace both. J4 now anchors the top of a real right-hand column; the
    5 zones fill in below it across 2 height-balanced columns, in their
    own functional order (not resorted by size), each row left-aligned to
    its column - a real grid, not a bin-pack. skyline_pa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
    [ClusterDisplay.kicad_pcb]
2026-09-27 display: undo the rigid column grid, fold J4 into CONTROL, tight-pack zones
    Direct user correction after the 2-column grid: "look at all the dead
    space. parts do not need to be in line." The grid fixed the floating-
    connector complaint by forcing every zone into aligned columns, but
    columns of very different real heights (module-anchored column A vs.
    J4-only column B) left two large dead rectangles - trading one problem
    for a worse one.
    Revert to a tight bin-pack for arranging zones around the module
    keepout (pack_sized_blocks restored), but keep the real fix for J4:
    instead of pulling it out as its own reserved block (which is what let
    it land disconnected from everything in the very first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
    [ClusterDisplay.kicad_pcb]
2026-09-27 display: real Toradex module keepout numbers, pack for min width not height
    Pulled Toradex's own Verdin Carrier Board Design Guide (docs.toradex.com/
    108140-verdin-carrier-board-design-guide.pdf) directly and read Figure
    110 (module outline) and Figure 114 (carrier board land pattern) rather
    than continuing to guess. Two real corrections:
    1. The module is 69.60 x 35.00mm, not 69.6 x 47mm - the 47mm figure
    came from an earlier, less authoritative web source. The module
    overhangs the connector's own real 27.1mm body by ~4mm/side on the
    width axis (confirmed centered, not assumed) and does NOT overhang
    it lengthwise (the connector's own 79mm housing is longer than the
    69.6mm mod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
    [ClusterDisplay.kicad_pcb]
2026-09-27 display: flatten zone-block packing to individual-component packing
    Direct user tradeoff: "break zone grouping for max density." The
    previous zone-block approach (each of the 5 functional zones packed
    internally, then the resulting rectangles packed around the module
    keepout) hit a real floor - board width couldn't shrink below the
    single widest zone's own packed width (POWER, 85.4mm) no matter how
    the zones were arranged relative to each other, since each was shaped
    into one rigid block before ever being placed.
    Replaced zone-block packing with a flat pack of all 72 individual real
    components directly, using the same transposed skyline technique
    (bound at the module's real 82mm height, min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
    [ClusterDisplay.kicad_pcb]
2026-09-27 gauges: route board and generate real BOM
    Routed ClusterGauges.kicad_pcb with FreeRouting (0 unrouted on the
    first attempt) plus post-route GND/+3V3 zone pours and VIN_PROT trunk
    widening, adapted from the top-level cluster-pcb/route_board.py.
    Found and fixed a real bug in the process: widen_trunks()'s
    TRACK_CLEARANCE was set to 0.15mm to match the netclass "clearance"
    field, but kicad-cli's actual enforced DRC minimum is 0.2mm (every
    .kicad_pro in this family leaves design_settings.rules.min_clearance
    unset, so KiCad falls back to its own stock default regardless of the
    netclass value). A first route+widen+zone pass produced 235 real
    clearance violations, all on widened VIN_PROT segments.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
    [ClusterGauges.kicad_pcb]
2026-09-27 display: route board and generate real BOM
    Added +12V_PROT trunk-widening constants (TRUNK_WIDTH_LADDER/
    TRUNK_NETS) to build_pcb.py - this board's own real fused/protected
    rail, feeding both the main +5V buck and the backlight boost converter,
    so it's sized toward F1's real 5A rating rather than reusing gauges/'s
    smaller 2A-fuse ladder.
    Routed ClusterDisplay.kicad_pcb with FreeRouting (0 unrouted on the
    first attempt) plus post-route GND/+5V zone pours (this board has no
    +3V3 net - +5V is the real widely-distributed second rail here) and
    +12V_PROT trunk widening, adapted from gauges/route_board.py. Same real
    TRACK_CLEARANCE fix applied (0.15 -> 0.2, see gauges/route_board.py's
    own comment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
    [ClusterDisplay.kicad_pcb, ClusterDisplay.kicad_sch]
2026-09-27 route_board.py: fix latent TRACK_CLEARANCE bug for consistency
    Same real fix as gauges/route_board.py and display/route_board.py:
    0.15mm matched the netclass "clearance" field, but kicad-cli's real
    DRC minimum is 0.2mm since this board's own .kicad_pro leaves
    design_settings.rules.min_clearance unset. This board (the superseded
    single-board design) never actually hit the bug since it was retired
    before a widened trunk got DRC'd against real neighboring copper at
    gauges/'s or display/'s own density - fixed here for consistency, not
    because this board is being re-routed.
    [route_board.py]
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2026-09-29 display: resolve 5 of 9 TBD BOM lines with real, cited parts
    Real part selection, each one researched and verified against its own
    real datasheet rather than guessed:
    - Q1/Q2 (front-end back-to-back FET pair): Nexperia PMV55ENEA (60V,
    VGS +-20V, 3.1A, SOT-23, AEC-Q101). Selected directly against
    LM74930-Q1's own datasheet (SNOSDF6) "MOSFET Q2 Selection" section,
    which states two real requirements: 60V VDS (matching this board's
    real single-TVS front end) and >=15V VGS rating (HGATE/DGATE can
    drive up to 14V) - PMV55ENEA satisfies both with real margin.
    Honestly flagged: its 3.1A continuous rating sits below F1's own 5A
    hold current; real steady-state current draw hasn't been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
    [ClusterDisplay.kicad_pcb, ClusterDisplay.kicad_sch]
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2026-10-02 Prepare both boards for fabrication: real power-stage values, orderable BOMs, fab packages
    display/ power stage was placeholders inherited from fascia-pcb (RILIM, OV top,
    RT, FB top...). Values are now calculated from the LM74930-Q1, LM61460-Q1 and
    TLV767-Q1 datasheets, with real packages (1u XEL5030 inductor, 1206 caps, 2 mohm
    sense resistor, polymer bulk cap). gauges/ buck inductor (XAL5050, Isat above the
    LMR33630 current limit) and input/output capacitors fixed per its datasheet.
    tools/passive_catalog.py maps every passive to a real MPN (entries flagged
    verified or pattern). fab/build_fab.py writes gerbers, drill, CPL and BOM CSVs
    and refuses boards with unconnected nets. Silkscreen text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
    [ClusterDisplay.kicad_pcb, ClusterDisplay.kicad_sch, ClusterGauges.kicad_pcb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]
2026-10-02 BOMs: list the screens (4x Raystar GC9A01, 1x TSD panel) and the Amphenol FPC connectors as orderable lines
    The cart CSVs skipped the screens: the TSD panel was a zero-quantity reference
    line, and the gauges BOM listed the Raystar module under the connector
    footprint with no separate connector. Now the connector and the screen are
    separate lines; the screens are marked companion parts ordered direct.
    [combined_bom.csv, display_bom.csv, gauges_bom.csv]
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2026-10-04 Fix review findings: MOSFET pinout, gauges surge front end, converter cells, DSI
    Review of 2026-10-03 found real defects; fixes and measured results:
    - Nexperia PMV55ENEA/PMV37ENEA pinout is G=1, S=2, D=3: display Q1-Q3 and
    gauges Q2 had source/drain swapped. Fixed in both schematics.
    - gauges/ now has the same LM74930-Q1 surge-protected front end as display/
    (5 mohm sense, OV clamp), a 5 A/32 V blade fuse on display/ (the MF-RG500 PTC
    was a 16 V part), and sender inputs with series resistor, clamp and filter.
    - Converters are placed as cells around their ICs (tools/cellplace.py).
    display: SW_5V 55.6 -> 11.6 mm, boost/inverter/backlight SW 75 -> 7-13 mm,
    LM61460 input caps 57 -> 4.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
    [ClusterDisplay.kicad_pcb, ClusterDisplay.kicad_sch, ClusterGauges.kicad_pcb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]
2026-10-04 gauges rev C: six 12 V-active indicator-lamp inputs and a tach input
    1966 Mustang lamps are 12 V-active (user-confirmed), tach input wanted.
    - J10 (7-pin KK 254): left/right turn, high beam, brake, alternator, oil + GND.
    Each input: 33k/15k divider, BAV99-Q clamp, 10 nF filter, DNP 4.7k pull-up
    for a ground-switched lamp (firmware inverts that channel).
    - J11 tach: two 18k 1206 (200 V) in series + 15k, 2.2 nF, clamp, DNP pull-up
    for open-collector outputs. Coil-negative use on a points system is not
    validated. MCU pins: tach = pin 57 (FTM1_CH5), lamps = pins 35/36/37/38/43/44.
    - Protocol: Indicators (0x303), InputConfig (0x420), RpmFromTach status bit.
    - Layout: new zone next to the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
    [ClusterGauges.kicad_pcb, ClusterGauges.kicad_sch, combined_bom.csv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]
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2026-10-09 display-rgb: copy of display/ with an LVDS-to-RGB bridge for a parallel-RGB round panel
    Variant for the Anders 4.2 in circular display (720x720, 1300 nits, RGB):
    - U9 TI DS90CF384AQ-Q1 (AEC-Q100 Grade 3, 20-65 MHz, TSSOP-56) fed by the
    Verdin LVDS0 channel, outputs 24-bit RGB + HS/VS/DE/PCLK; pin table and bit
    mapping read from TI SNLS345A; orderable DS90CF384AQMTX/NOPB (Active).
    - U10 TLV733P-Q1 3.3 V LDO, 100 ohm LVDS terminations, decoupling, and a
    PLACEHOLDER 50-pin FPC (J14) because the panel datasheet is not in yet.
    - SPI_1 and GPIO_2 routed to the panel connector for setup and reset.
    ERC 0 violations, BOM coverage OK. NOT routed: eight autorouter pipelines never
    reached 0 unconn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
2026-10-15 software: stub tree for the gauges firmware and the Android side; fix invalid 1f literal in the generated C header
    - software/gauges-fw: S32K144 skeleton (pins header from the schematic, main loop,
    stubs for senders, inputs, CAN link, aux display, power). aggregate.c is real:
    source priority (Hall vs car-bus speed, tach vs car-bus RPM, car vs local
    fluids) with host unit tests that pass under gcc in WSL; all stubs compile
    with -Wall -Wextra -Werror against the generated cluster_can.h.
    - software/android: README-level plan for the VHAL bridge, cluster app and
    rotary service (property mapping marked TO VERIFY against AOSP).
    - protocol/can_protocol.py: factor 1 was emitted as the C li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
